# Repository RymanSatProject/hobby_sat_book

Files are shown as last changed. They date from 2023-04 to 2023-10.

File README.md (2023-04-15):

# #趣味で作る人工衛星

本リポジトリは、[オーム社 #趣味で作る人工衛星](https://www.ohmsha.co.jp/book/9784274230387/)のサポートページです。

## 構成

### [00_errata](00_errata)

書籍の正誤表が入っています。

### [01_CDH_OBC](01_CDH_OBC)

第7章C&DH系OBCソフトウェアのソースコード

### [02_Mission_OBC](02_Mission_OBC)

第7章ミッションOBCソフトウェアのソースコードおよびセットアップスクリプトが入っています。

### [03_Telecom_OBC](03_Telecom_OBC)

第7章通信OBCソフトウェアのソースコードが入っています。

### [04_Ground_Sta](04_Ground_Sta)

第7章地上局ソフトウェアのインストーラが入っています。

### [05_Schematic](05_Schematic)

第7章EM基板のKiCadファイルが入っています。回路図とCAD画像も入れてあるので、基板作成時にご参照ください。

### [10_Ch7_Sup](10_Ch7_Sup)

第7章の各種補足説明が入っています。

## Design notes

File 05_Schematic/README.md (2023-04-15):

# 回路図面

書籍で作成する基板の回路図を保存しています。使用ソフトウエアはKiCAD (https://www.kicad.org/download/) です。Version6.0以降であれば問題ないと思います。
基板制作時の部品配置や配線の参考にご利用ください。

RaspberryPi RaspberryPiの搭載されている下部基板の図面です。

esp32 Esp32の搭載されている背面基板の図面です。

stm32 STM32の搭載されている上部基板の図面です。

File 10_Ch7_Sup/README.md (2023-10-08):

# 第7章 補足説明

本フォルダ、第7章を進めるにあたって必要なソフトウェアの説明及び補足情報が入っています。

- 購入部品・工具リスト(代替部品記載有り): [こちら(Excel)](parts/RSP-01Lite_Parts_ToolList.xlsx)
- C系ソフトウェア: [sw-c.md](sw-c.md)
- T系ソフトウェア: [sw-t.md](sw-t.md)
- T系OBCとPCとの接続設定: [sw-t-pc.md](sw-t-pc.md)
- ターミナルについて: [sw-terminal.md](sw-terminal.md)
- Raspberry Pi Zeroの設定について: [pi-setting.md](pi-setting.md)
- コマンドリスト: [こちら(Excel)](design/RSP-01Lite_CommandList.xlsx)

## P144 図9でBMX055表示が出ない場合

### 1.STM32のリセットボタンを押す

STM32のB2（黒いボタン）を押すことでリセットがかかり、表示される場合があります。表示されない場合は配線が間違っている可能性があるので、もう一度配線を見直してください。

## P178 図66の組み上げ後、アームが動かない場合

### 1.モーターにコンデンサを追加する

モーターのノイズをI2Cが引き込んで動作しにくい場合があります。モーターに0.1μFのコンデンサを3個はんだ付けして見て下さい。参考写真[こちら](img/P178_fig66.jpg)

### 2.ギア、軸受けにグリスを塗布する

ギアボックスの各種ギアやシャフトの軸受けにグリスを塗布することで負荷が減ります。参考[タミヤ モリブデングリス](https://www.tamiya.com/japan/products/87022/index.html)

## P150 apt update で 404 Not Found が発生する場合
2023/10/7 時点で、``` apt update ``` を行うと以下のエラーメッセージが表示されます。

```
$ sudo apt update && sudo apt upgrade -y

Hit:1 http://archive.raspberrypi.org/debian stretch InRelease
Ign:2 http://raspbian.raspberrypi.org/raspbian stretch InRelease
Err:3 http://raspbian.raspberrypi.org/raspbian stretch Release
  404  Not Found
Reading package lists... Done
E: The repository 'http://raspbian.raspberrypi.org/raspbian stretch Release' does no longer have a Release file.
N: Updating from such a repository can't be done securely, and is therefore disabled by default.
N: See apt-secure(8) manpage for repository creation and user configuration details.
```

上記が発生した場合は、リポジトリの参照先を変更する必要があります。

```
# sources.list を開く
sudo vi /etc/apt/sources.list
```

以下のようにリポジトリの参照先を変更します。

```
#deb http://raspbian.raspberrypi.org/raspbian/ stretch main contrib non-free rpi
deb http://legacy.raspbian.org/raspbian/ stretch main contrib non-free rpi
```

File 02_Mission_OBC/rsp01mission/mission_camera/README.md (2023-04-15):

## 概要
Raspberry Pi上で動作するMission系のカメラ機能。自撮りや画像等の送信を行う。

## 必要なもの
pillowに以下のライブラリが必要
```
sudo apt-get install libopenjp2-7
```

## コーディング規則
- 文字コードはUTF-8とする。
- IntelliJ IDEAでオートフォーマットをかけるのをおすすめします。Option + Cmd + L(WindowsではAlt + Ctrl + L)

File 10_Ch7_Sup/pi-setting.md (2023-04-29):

# Raspberry Pi Zeroの設定について

Raspberry Pi Zeroの設定に関する補足事項などについて説明します。

## 1. IPアドレス
### 1.1 静的IPアドレスの設定
書籍では、Raspberry Pi ZeroのIPアドレス設定はデフォルトであるdhcpとなっています。dhcpの場合、Windowsとのインターネット共有の際にインターネット接続が可能となるまで１、２分かかる場合があります。   
静的IPアドレスの設定を行うことで、Raspberry Pi Zeroの起動後、ほぼ即座にインターネット接続状態になります。

静的IPアドレスの設定は以下の手順で行います。

1. sshなどでRaspberry Pi Zeroに接続します。
2. 以下コマンドで /etc/dhcpcd.conf を開きます。
```bash
sudo vi /etc/dhcpcd.conf
```
3. 「Example static IP configuration:」の下、47行目周辺に以下を追記し、保存終了します。（vi の操作方法はここでは割愛します）

```
interface usb0
static ip_address=192.168.137.10
static routers=192.168.137.1
static domain_name_servers=8.8.8.8
```

※routersのアドレスは、Windows側のUSB EthernetデバイスのIPアドレスを設定する事になります。（デフォルトで192.168.137.1が設定されます）   
※DNSはGoogle社のDNSを指しています。

4. 以下コマンドで /etc/network/interfaces を開きます。
```bash
sudo vi /etc/network/interfaces
```

5. ファイル末尾に以下を追記し、保存終了します。
```
auto lo usb0
allow-hotplug usb0
iface usb0 inet manual
```

6. Raspberry Pi Zeroを以下コマンドで再起動します。
```
sudo reboot
```

7. 再起動後、以下コマンドでIPアドレスの設定状態を確認します。
```
ip a
```

以下のように usb0 のIPアドレスが 192.168.137.10/24 で表示されることを確認します。

```
pi@raspberrypi:~$ ip a
1: lo: <LOOPBACK,UP,LOWER_UP> mtu 65536 qdisc noqueue state UNKNOWN group default qlen 1000
    link/loopback 00:00:00:00:00:00 brd 00:00:00:00:00:00
    inet 127.0.0.1/8 scope host lo
       valid_lft forever preferred_lft forever
    inet6 ::1/128 scope host
       valid_lft forever preferred_lft forever
2: usb0: <BROADCAST,MULTICAST,UP,LOWER_UP> mtu 1500 qdisc pfifo_fast state UP group default qlen 1000
    link/ether d6:ed:b2:e8:fc:2f brd ff:ff:ff:ff:ff:ff
    inet 192.168.137.10/24 brd 192.168.137.255 scope global usb0
       valid_lft forever preferred_lft forever
    inet6 fe80::d4ed:b2ff:fee8:fc2f/64 scope link
       valid_lft forever preferred_lft forever
```

8. pingでインターネット接続を確認します。
```
ping rymansat.com
```

以下のような応答が得られることを確認します。

```
64 bytes from www2944.sakura.ne.jp (49.212.198.184): icmp_seq=1 ttl=55 time=12.2 ms
64 bytes from www2944.sakura.ne.jp (49.212.198.184): icmp_seq=2 ttl=55 time=12.3 ms
```

## 2. インターネット接続
### 2.1 WindowsとRaspberry Piのインターネット接続の共有

インターネット接続の共有は、Windowsを再起動すると解除されます。   
再起動後もインターネット接続の共有を維持する場合は、以下の設定を行います。

1. Power Shell を管理者権限で起動します。
2. 以下のコマンドを実行します。
```
# レジストリにインターネット接続共有の永続化を設定する
New-ItemProperty -Path HKLM:\Software\Microsoft\Windows\CurrentVersion\SharedAccess -Name EnableRebootPersistConnection -Value 1 -PropertyType dword

# 「Internet Connection Sharing (ICS)」サービスを自動起動に変更する
Set-Service SharedAccess -StartupType Automatic -PassThru
```

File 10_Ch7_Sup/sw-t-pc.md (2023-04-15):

# 開発環境準備（ソフトウェア）: 通信: PCとのBluetooth接続

T系OBCとPCとのBluetooth接続の方法について説明します。

## T系OBCとPCの接続

T系OBCの電源を入れます。

PCの「設定」を開き、「デバイス」を選択します。

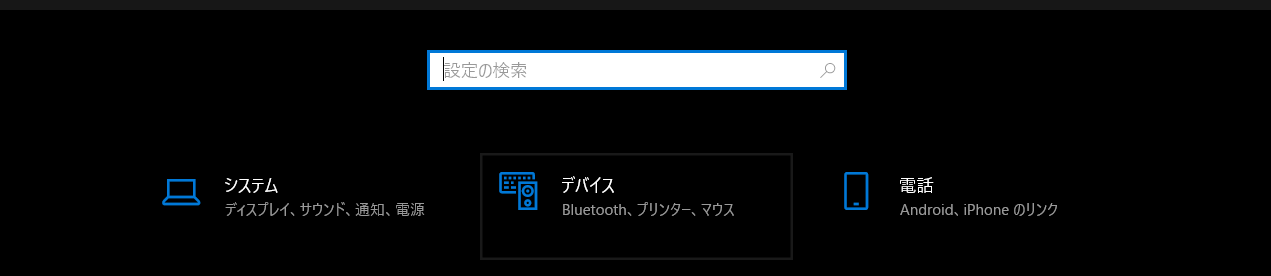
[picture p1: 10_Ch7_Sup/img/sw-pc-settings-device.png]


「Bluetoothまたはその他のデバイスを追加する」を選択します。

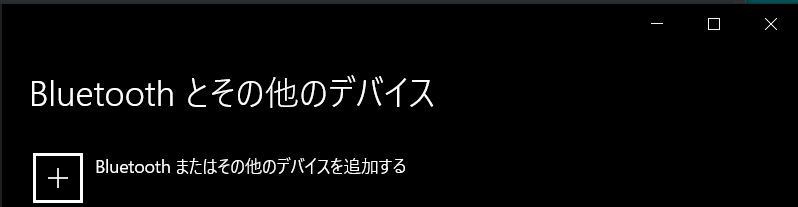
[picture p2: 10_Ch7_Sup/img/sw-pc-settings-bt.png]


「デバイスを追加する」ウィンドウで「Bluetooth」を選択します。

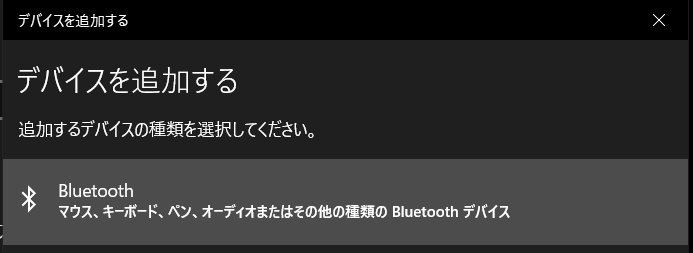
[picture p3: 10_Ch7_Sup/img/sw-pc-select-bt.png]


「01-lite」を選択すると接続開始します。うまくいくと以下のようになるので、「完了」をクリックしてウィンドウを閉じます。

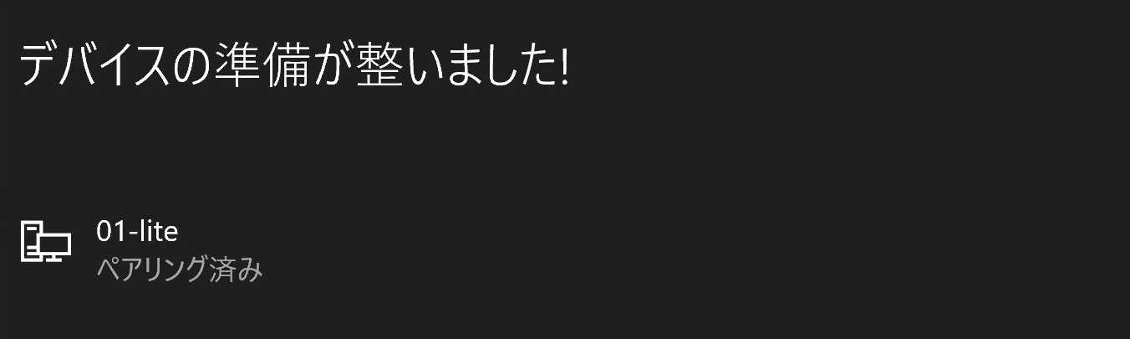
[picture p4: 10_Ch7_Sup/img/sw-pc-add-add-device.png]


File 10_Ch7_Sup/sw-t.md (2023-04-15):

# 開発環境準備（ソフトウェア）: 通信

T系OBC用ソフトウェアのビルド環境・ビルド実行・T系OBCへのインストールの方法について説明します。

# ビルド環境の準備

通信ソフトウェアはArduinoライブラリを利用しています。これのビルドとT系OBCへのアップロードにはArduino IDEを使用します。

## Arduino IDEのインストール

[https://www.arduino.cc/en/software](https://www.arduino.cc/en/software) に行き、「DOWNLOAD OPTIONS」のうち「Windows Win 10 and newer, 64 bits」を選択してダウンロード・インストールします。

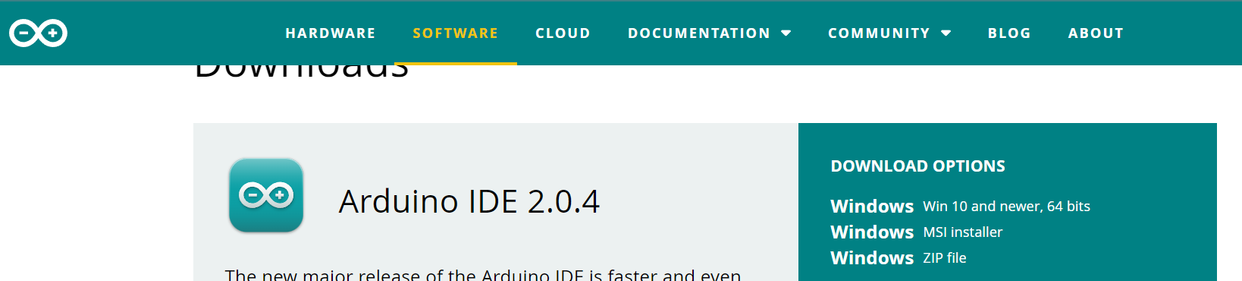
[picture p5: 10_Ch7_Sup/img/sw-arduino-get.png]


インストール後、スタートメニューから「Arduino IDE」をクリックして起動します。

起動後、以下の画面が現れたら、「プライベートネットワーク」の方にチェックを入れて「アクセスを許可する」をクリックします。

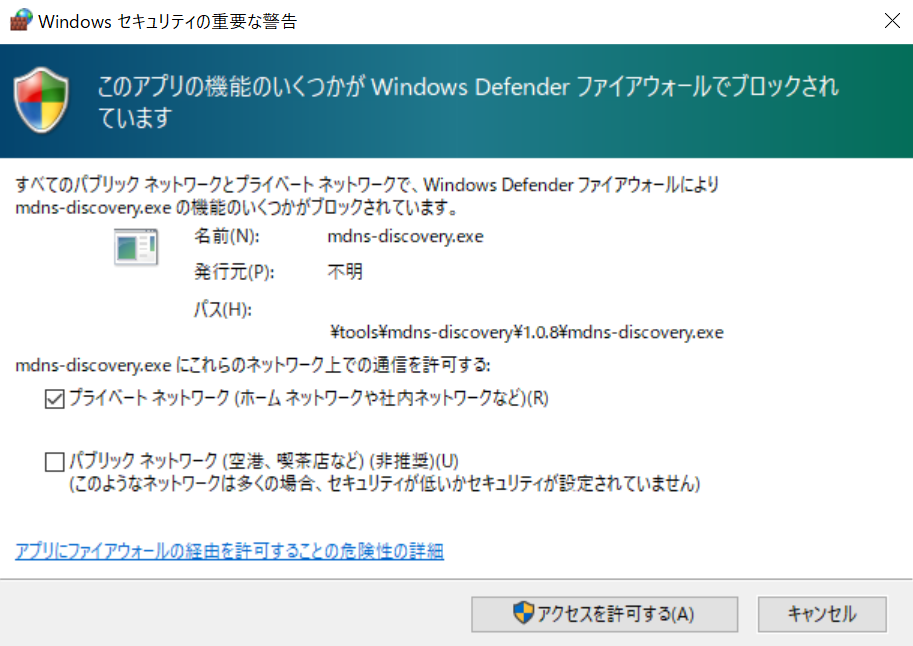
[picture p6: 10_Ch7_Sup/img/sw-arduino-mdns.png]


また、以下のようにいくつかインストールが求められますが、いずれも「インストール」を選択しておきます。

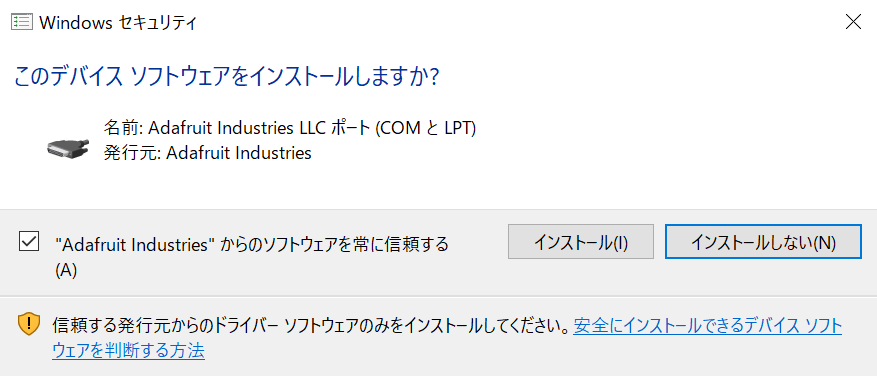
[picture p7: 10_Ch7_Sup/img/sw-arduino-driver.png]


最後に、Arduino IDEのメニューバーで「File」→「Preferences」をクリックし、設定画面を開きます。

表示言語を日本語に変更するため、「Language」で「日本語」を選択して「OK」をクリックします。

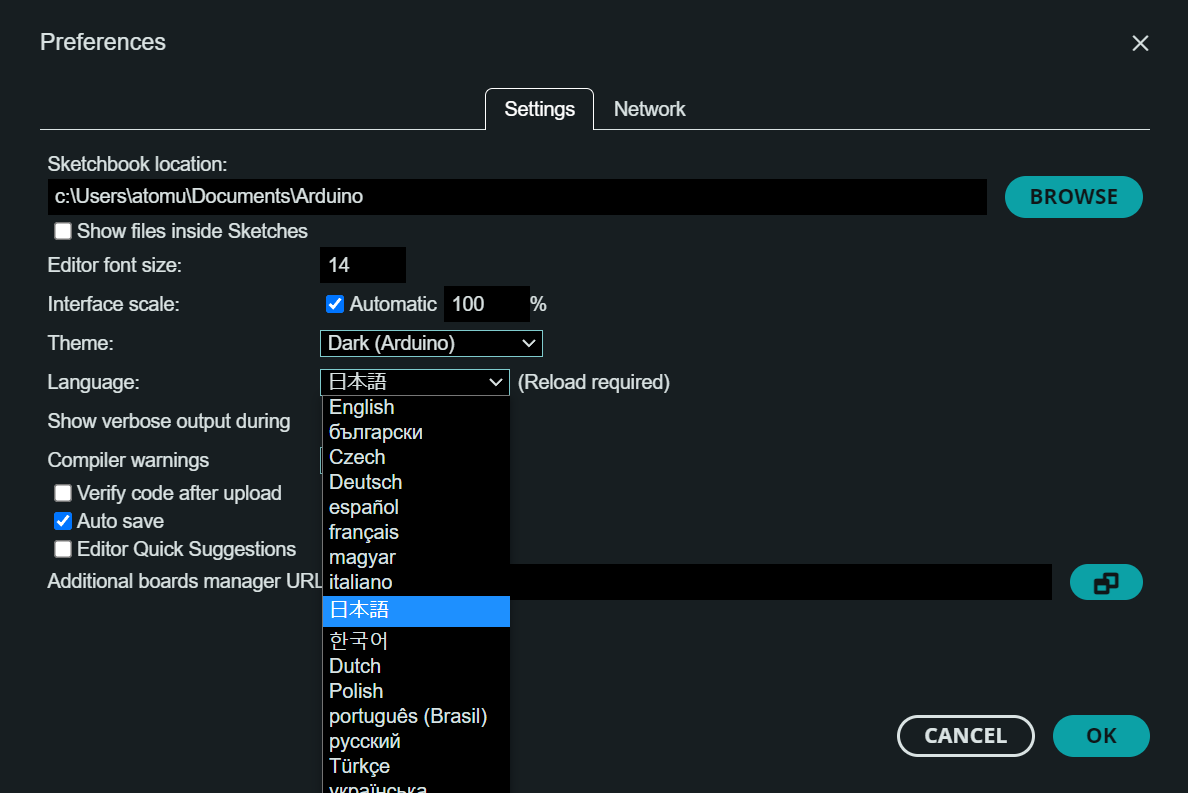
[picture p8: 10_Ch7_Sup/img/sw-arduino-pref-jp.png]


するとArduino IDEが自動的に再起動し、表示が日本語に切り替わります。

## ライブラリの追加

通信ソフトウェアで利用されるarduino-esp32ライブラリインストールします。

[https://docs.espressif.com/projects/arduino-esp32/en/latest/installing.html](https://docs.espressif.com/projects/arduino-esp32/en/latest/installing.html) にアクセスし、「Stable release link」に記載されたURLをコピーします。（本稿執筆段階でのURLは`https://raw.githubusercontent.com/espressif/arduino-esp32/gh-pages/package_esp32_index.json`です）

続けて、Arduino IDEのメニューバーで「ファイル」→「基本設定...」をクリックし、設定画面を開きます。

「追加のボードマネージャのURL」に先程コピーしたURLを貼り付け、「OK」をクリックします。

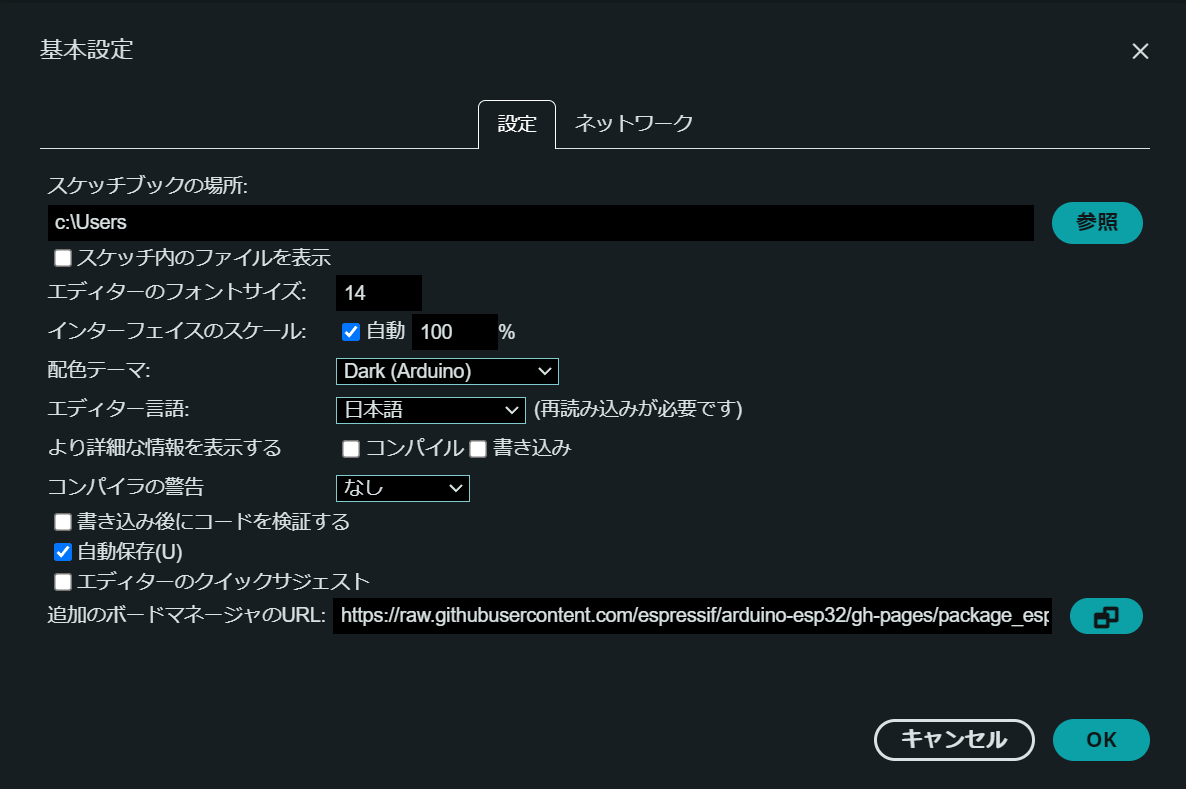
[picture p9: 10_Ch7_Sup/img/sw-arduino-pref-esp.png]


その後、Arduino IDEのメニューバーで「ツール」→「ボード」→「ボードマネージャ」をクリックし、ボードマネージャを開きます。

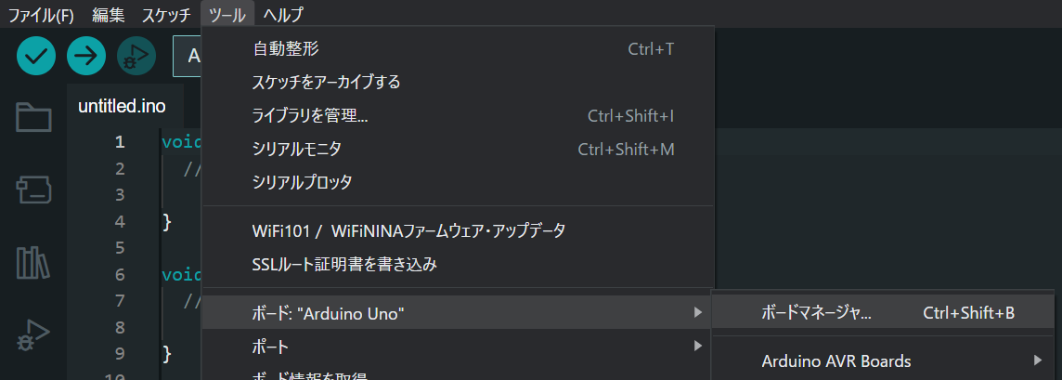
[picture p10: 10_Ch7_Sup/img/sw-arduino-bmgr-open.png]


この中から「esp32 by Espressif Systems」を見つけます（「es」と検索するとすぐに出てきます）。そして図のようにバージョン2.0.2を選択して「インストール」をクリックします。（クリックするとバージョン選択が元に戻りますが、インストールされるのは選択した2.0.2となります）

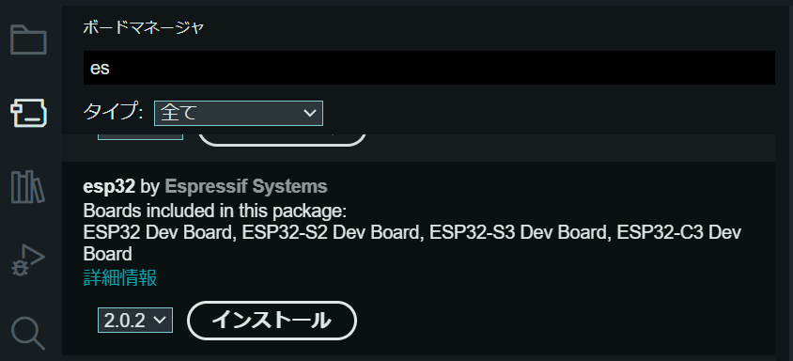
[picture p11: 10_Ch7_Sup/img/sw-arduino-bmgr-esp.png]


## ソースコードの取得

以下のいずれかの方法でソースコードを取得します。

### GitHubからzipファイルをダウンロードする

本GitHubページのトップで「Code」をクリックし、「Download ZIP」でzipファイルをダウンロード・解凍します。

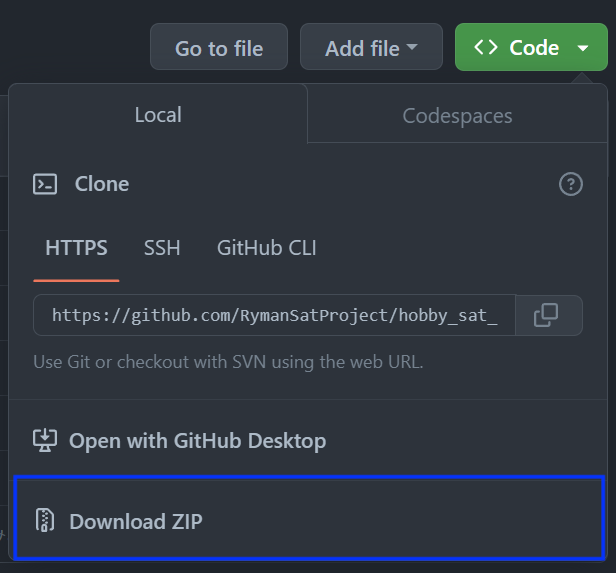
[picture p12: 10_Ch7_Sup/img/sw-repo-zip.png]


### `git`コマンドを使う

[開発環境準備（ソフトウェア）: C系](sw-c.md)に記述のようにUbuntuを導入済みの場合は、`git`コマンドを使って**Windows側のファイルシステムに**リポジトリを取得できます。

```bash
# Windows側に移動する。移動先が「ドキュメント」フォルダの場合は以下
cd /mnt/c/Users/user/Documents

# リポジトリを取得
git clone https://github.com/RymanSatProject/hobby_sat_book.git
```

（**注意**: Arduino IDEは、WSL上のLinuxファイルシステム配下のソースファイルを開くことができません。ソースファイルはWindowsのファイルシスステム配下に直接置く必要があります。）

# ビルドの実行

エクスプローラで取得したフォルダ中の`03_Telecom_OBC\esp32\esp32.ino`をArduino IDEで開きます。

下図のように、Arduino IDEのメニューバーで「ツール」→「ボード」→「esp32」とたどり、「ESP32 Dev Module」をクリックします。

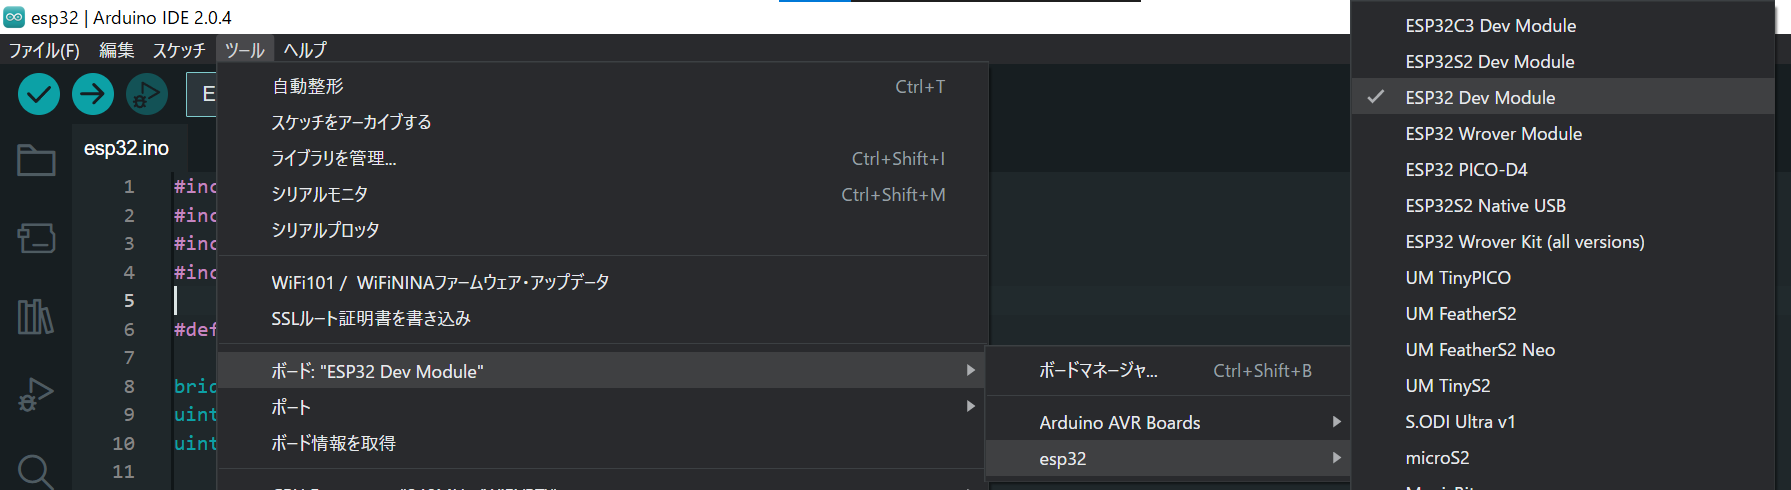
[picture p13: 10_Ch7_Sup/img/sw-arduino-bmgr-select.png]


そして画面左上のチェックマークをクリックするか、`Ctrl + r` でビルドを実行します。ビルドには1分程度の時間がかかります。

画面下側の黒い出力画面で

```text
最大1310720バイトのフラッシュメモリのうち、スケッチが259073バイト（19%）を使っています。
最大327680バイトのRAMのうち、グローバル変数が19356バイト（5%）を使っていて、ローカル変数で308324バイト使うことができます。
```

のように出力されれば成功です。

# アップロード

まず、T系OBCをPCから外した状態で、Arduino IDEのメニューバーの「ツール」→「シリアルポート」にマウスを移動し、どのポートが存在するか確認します。

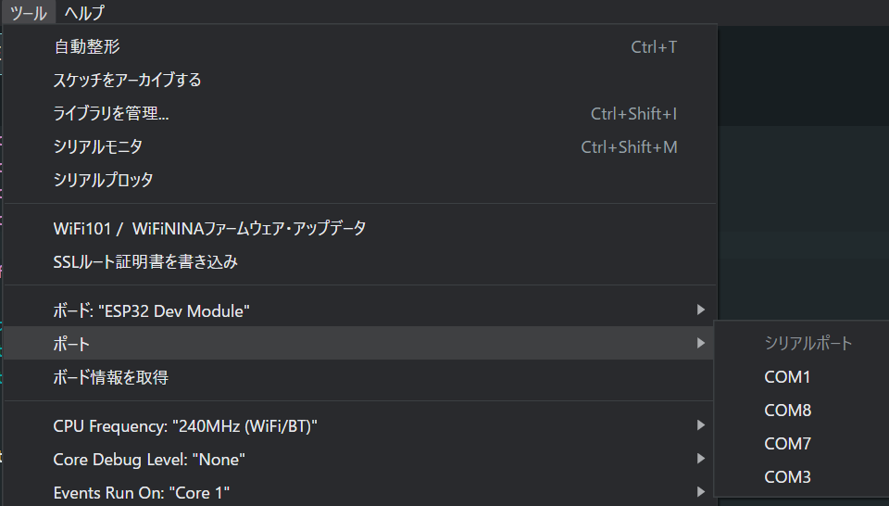
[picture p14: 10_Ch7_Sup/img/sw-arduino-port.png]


続けてT系OBCとPCをUSBケーブルで接続し、同じように「ツール」→「シリアルポート」を確認します。PCがESP32を正しく認識していると、下図のようにポートが1つ増えているはずです。

この新しく増えたポートをクリックし、書き込み先ポートを決定します。

ポートが追加されていない場合は、PCがT系OBCを認識していない可能性があります。この場合はT系OBCをPCから外し、再度接続してみてください。

続けて、画面左上の右矢印ボタンを押すか、`Ctrl + u`を押すと、プログラムのビルドとアップロードが始まります。

「出力」に

```text
Leaving...
Hard resetting via RTS pin...
```

と表示されれば書き込み成功です。

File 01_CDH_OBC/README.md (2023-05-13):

# 簡易RSP-01 Main OBCソフトウェア

本ディレクトリには、第7章のMain OBC用ソフトウェアのソースコードが格納されています。

このソフトウェアは、RSP-01における実装を参考に書き直しを行ったものです。

環境設定・ビルドの方法は[10_Ch7_Sup/sw-c.md](/10_Ch7_Sup/sw-c.md)を参照ください。

## ターミナルでの文字入力

Main OBCにT系OBCが接続されていないか、T系OBCとの接続が不安定な場合、ターミナルには通信失敗を示す以下のようなメッセージが約1秒周期で表示されます:

```text
[ERR] comm.handshake: timeout
[ERR] transact: failed: cmd=0x10 ret=1
```

このとき、キーボードからの入力の取りこぼしが発生しやすくなります。取りこぼしを回避するためには、上記メッセージの合間に1文字ずつ入力してください。

文字入力に成功すると、入力文字がエラーメッセージの間に割り込む形で表示されます。下図は`debug 1`の入力に成功した場合の例です:

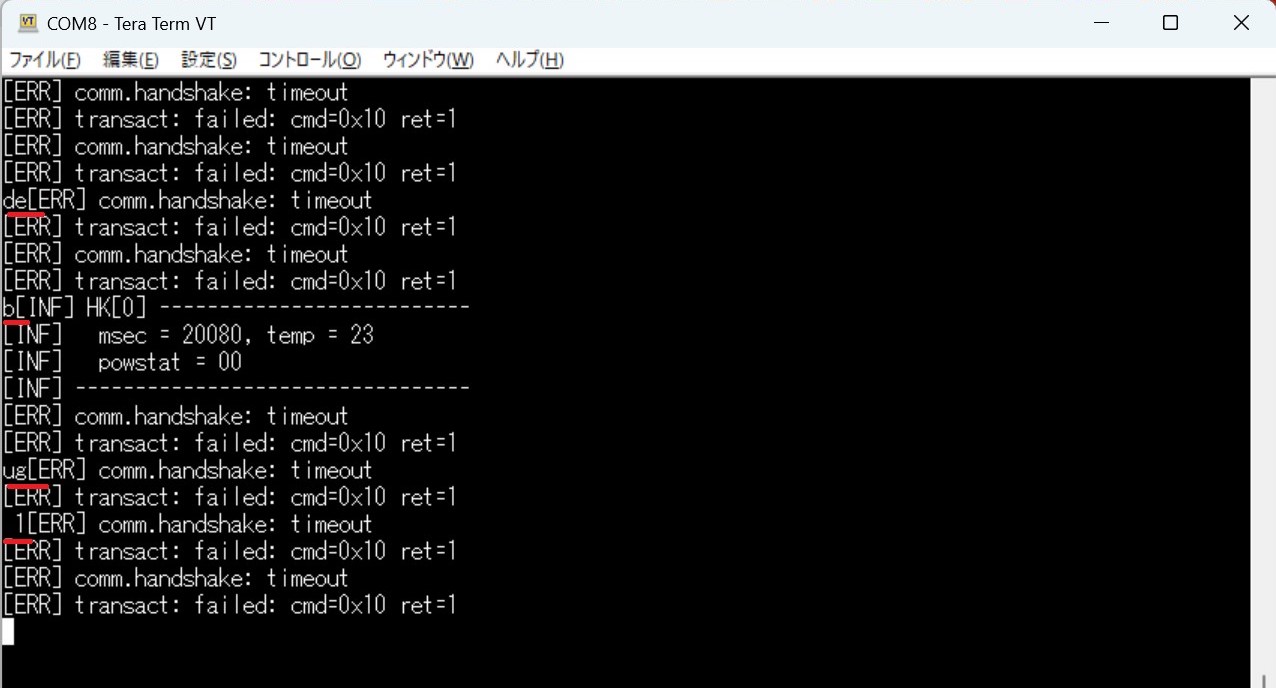
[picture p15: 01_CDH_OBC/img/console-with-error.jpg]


入力した文字が表示されない場合は取りこぼしが発生しているので、エラーメッセージの合間に`Ctrl + c`を入力して入力をキャンセルし、再度入力を試みてください。

## 設定の変更

### アームのパラメータ変更

`src/config/config.hpp`には、アームの挙動に関係するいくつかのパラメータが定義されています。必要に応じて変更してください。

- `DRIVE_FORWARD_LIMIT`, `DRIVE_REVERSE_LIMIT`:
  - アーム展開・収納時に、アーム駆動部（書籍図62中の３番パーツで構成される部分）が軸（書籍図62中の25番パーツ）に対してどの程度端まで到達するかを決めるパラメータです。0は完全に展開しきった位置、65535は完全に収納しきった位置を示します。
  - 値の範囲は以下に従ってください:
    - 0以上65535以内
    - 大きさの関係: `DRIVE_FORWARD_LIMIT` < `DRIVE_REVERSE_LIMIT`
  - 例えば、アームの展開長を小さくしたい場合は`DRIVE_FORWARD_LIMIT`をより大きな値にしてください。

- `DRIVE_TIME_MS`: 1回の展開/収納動作に使われる最大継続時間（ミリ秒）。駆動時間が長すぎる・短すぎる場合は変更してください

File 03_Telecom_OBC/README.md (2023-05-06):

# 簡易RSP-01 T系OBCソフトウェア

本ディレクトリには、第7章のT系OBC用ソフトウェアのソースコードが格納されています。

このソフトウェアは、RPS-01における実装を参考に書き直しを行ったものです。

環境設定・ビルドの方法は[10_Ch7_Sup/sw-t.md](/10_Ch7_Sup/sw-t.md)を参照ください。

PCとのBluetooth接続の方法については[10_Ch7_Sup/sw-t-pc.md](/10_Ch7_Sup/sw-t-pc.md)を参照ください。

## 設定の変更

### ブザーの音量を小さくする

ブザーの音量は、`esp32/src/common/config.hpp`中の`CW_VOLUME_PERCENT`で設定されます。音を大きくするには100までの大きな値を、小さくするには0以上の小さな値を設定し、再度ビルド・アップロードしてください。

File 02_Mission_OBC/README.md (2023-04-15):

# ミッション系

本ディレクトリには、第7章のM系Raspberry Pi Zeroにインストールするソフトウェアが格納されています。   
書籍の手順に従い、ZIPファイルをダウンロードし、インストールを行ってください。

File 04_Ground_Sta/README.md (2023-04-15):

# 地上局

本ディレクトリには、第7章の地上局ソフトウェアである「TestCamp Lite（テストキャンプ ライト）」が格納されています。

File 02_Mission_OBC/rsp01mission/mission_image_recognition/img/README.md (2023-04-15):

# 切り出しメモ
## Earth Seen From Space Station ISS [Real Speed HD].mp4

```bash
ffmpeg -ss 192 -i Earth\ Seen\ From\ Space\ Station\ ISS\ \[Real\ Speed\ HD\].mp4 -t 100 ../001.mp4
ffmpeg -ss 400 -i Earth\ Seen\ From\ Space\ Station\ ISS\ \[Real\ Speed\ HD\].mp4 -t 80 ../002.mp4
ffmpeg -ss 705 -i Earth\ Seen\ From\ Space\ Station\ ISS\ \[Real\ Speed\ HD\].mp4 -t 90 ../003.mp4
ffmpeg -ss 833 -i Earth\ Seen\ From\ Space\ Station\ ISS\ \[Real\ Speed\ HD\].mp4 -t 80 ../004.mp4
ffmpeg -ss 1068 -i Earth\ Seen\ From\ Space\ Station\ ISS\ \[Real\ Speed\ HD\].mp4 -t 80 ../005.mp4
ffmpeg -ss 1388 -i Earth\ Seen\ From\ Space\ Station\ ISS\ \[Real\ Speed\ HD\].mp4 -t 60 ../006.mp4
```

## 国際宇宙ステーション（ISS）から撮影した夜の地球 【Full HD 1080p】.mp4

```bash
ffmpeg -ss 30 -i 国際宇宙ステーション（ISS）から撮影した夜の地球\ 【Full\ HD\ 1080p】.mp4 -t 13 ../007.mp4
ffmpeg -ss 140 -i 国際宇宙ステーション（ISS）から撮影した夜の地球\ 【Full\ HD\ 1080p】.mp4 -t 17 ../008.mp4
ffmpeg -ss 159 -i 国際宇宙ステーション（ISS）から撮影した夜の地球\ 【Full\ HD\ 1080p】.mp4 -t 9 ../009.mp4
ffmpeg -ss 170 -i 国際宇宙ステーション（ISS）から撮影した夜の地球\ 【Full\ HD\ 1080p】.mp4 -t 14 ../010.mp4
ffmpeg -ss 198 -i 国際宇宙ステーション（ISS）から撮影した夜の地球\ 【Full\ HD\ 1080p】.mp4 -t 12 ../011.mp4
ffmpeg -ss 225 -i 国際宇宙ステーション（ISS）から撮影した夜の地球\ 【Full\ HD\ 1080p】.mp4 -t 8 ../012.mp4
ffmpeg -ss 235 -i 国際宇宙ステーション（ISS）から撮影した夜の地球\ 【Full\ HD\ 1080p】.mp4 -t 6 ../013.mp4
ffmpeg -ss 243 -i 国際宇宙ステーション（ISS）から撮影した夜の地球\ 【Full\ HD\ 1080p】.mp4 -t 15 ../014.mp4
ffmpeg -ss 270 -i 国際宇宙ステーション（ISS）から撮影した夜の地球\ 【Full\ HD\ 1080p】.mp4 -t 15 ../015.mp4
```

## 【 ISS 】 国際宇宙ステーション 日本上空を飛行.mp4
全編を 016.mp4 として使う

## 宇宙から撮影された地球【Full HD 1080p】.mp4

```bash
ffmpeg -ss 165 -i 宇宙から撮影された地球【Full\ HD\ 1080p】.mp4 -t 23 ../017.mp4
ffmpeg -ss 730 -i 宇宙から撮影された地球【Full\ HD\ 1080p】.mp4 -t 51 ../018.mp4
ffmpeg -ss 730 -i fin/宇宙から撮影された地球【Full\ HD\ 1080p】.mp4 -t 19 ../018_1.mp4
ffmpeg -ss 750 -i fin/宇宙から撮影された地球【Full\ HD\ 1080p】.mp4 -t 30 ../018_2.mp4
ffmpeg -ss 796 -i 宇宙から撮影された地球【Full\ HD\ 1080p】.mp4 -t 20 ../019.mp4
ffmpeg -ss 864 -i 宇宙から撮影された地球【Full\ HD\ 1080p】.mp4 -t 15 ../020.mp4
ffmpeg -ss 881 -i 宇宙から撮影された地球【Full\ HD\ 1080p】.mp4 -t 20 ../021.mp4
ffmpeg -ss 911 -i 宇宙から撮影された地球【Full\ HD\ 1080p】.mp4 -t 15 ../022.mp4
ffmpeg -ss 928 -i 宇宙から撮影された地球【Full\ HD\ 1080p】.mp4 -t 16 ../023.mp4
```

## NASA - Earth view from ISS - 1080p60 HD - (time lapse).mp4

```bash
ffmpeg -ss 13 -i NASA\ -\ Earth\ view\ from\ ISS\ -\ 1080p60\ HD\ -\ \(time\ lapse\).mp4 -t 23 ../024.mp4
ffmpeg -ss 43 -i NASA\ -\ Earth\ view\ from\ ISS\ -\ 1080p60\ HD\ -\ \(time\ lapse\).mp4 -t 13 ../025.mp4
ffmpeg -ss 346 -i NASA\ -\ Earth\ view\ from\ ISS\ -\ 1080p60\ HD\ -\ \(time\ lapse\).mp4 -t 54 ../026.mp4
ffmpeg -ss 441 -i NASA\ -\ Earth\ view\ from\ ISS\ -\ 1080p60\ HD\ -\ \(time\ lapse\).mp4 -t 16 ../027.mp4
ffmpeg -ss 467 -i NASA\ -\ Earth\ view\ from\ ISS\ -\ 1080p60\ HD\ -\ \(time\ lapse\).mp4 -t 19 ../028.mp4
ffmpeg -ss 496 -i NASA\ -\ Earth\ view\ from\ ISS\ -\ 1080p60\ HD\ -\ \(time\ lapse\).mp4 -t 15 ../029.mp4
ffmpeg -ss 589 -i NASA\ -\ Earth\ view\ from\ ISS\ -\ 1080p60\ HD\ -\ \(time\ lapse\).mp4 -t 18 ../030.mp4
ffmpeg -ss 607 -i NASA\ -\ Earth\ view\ from\ ISS\ -\ 1080p60\ HD\ -\ \(time\ lapse\).mp4 -t 3 ../031.mp4
ffmpeg -ss 732 -i NASA\ -\ Earth\ view\ from\ ISS\ -\ 1080p60\ HD\ -\ \(time\ lapse\).mp4 -t 3 ../032.mp4
ffmpeg -ss 753 -i NASA\ -\ Earth\ view\ from\ ISS\ -\ 1080p60\ HD\ -\ \(time\ lapse\).mp4 -t 27 ../033.mp4
ffmpeg -ss 960 -i NASA\ -\ Earth\ view\ from\ ISS\ -\ 1080p60\ HD\ -\ \(time\ lapse\).mp4 -t 18 ../034.mp4
ffmpeg -ss 984 -i NASA\ -\ Earth\ view\ from\ ISS\ -\ 1080p60\ HD\ -\ \(time\ lapse\).mp4 -t 14 ../035.mp4
ffmpeg -ss 1130 -i NASA\ -\ Earth\ view\ from\ ISS\ -\ 1080p60\ HD\ -\ \(time\ lapse\).mp4 -t 27 ../036.mp4
ffmpeg -ss 1506 -i NASA\ -\ Earth\ view\ from\ ISS\ -\ 1080p60\ HD\ -\ \(time\ lapse\).mp4 -t 35 ../037.mp4
```

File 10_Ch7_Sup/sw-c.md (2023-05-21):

# 開発環境準備（ソフトウェア）: C系

Main OBC用ソフトウェアのビルド環境・ビルド実行・Main OBCへのインストールの方法について説明します。

# ビルド環境の準備

C系ソフトウェアのビルド環境は、WindowsのWindows Subsystem for Linux (WSL) という機能を使って構築します。

本作業は1時間〜数時間程度の時間がかかります。一度完了すれば、ほとんどの工程は繰り返す必要はありません。

すでに同様の環境およびツールがインストール済みの場合は、適宜スキップしてください。

## Ubuntuのインストール

### Linux機能の有効化

「Windowsの機能の有効化または無効化」を開きます。

「スタート」（Windowsマーク）をクリックし、そのまま半角入力モードで「windows」と入力します。すると、下図のように「Windowsの機能の有効化または無効化」が現れるので、それをクリックして開きます。

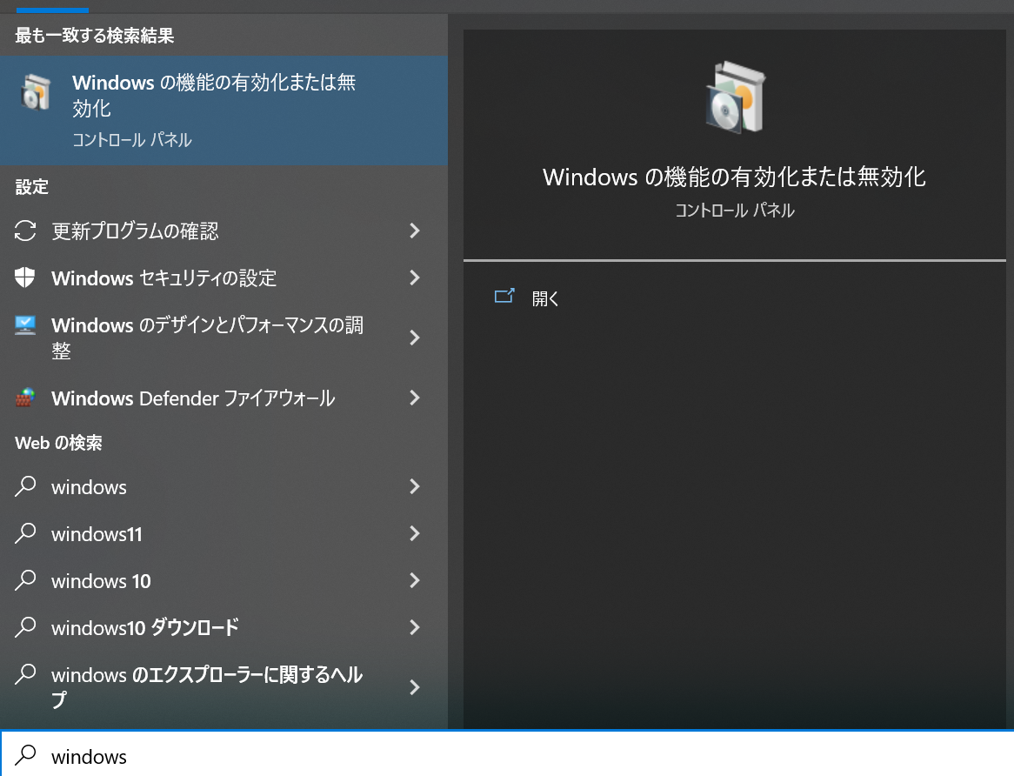
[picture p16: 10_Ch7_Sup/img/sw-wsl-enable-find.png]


以下の2つの項目を見つけ、それぞれチェックマークを入れます:

- 「Linux用Windowsサブシステム」
- 「仮想マシン プラットフォーム」

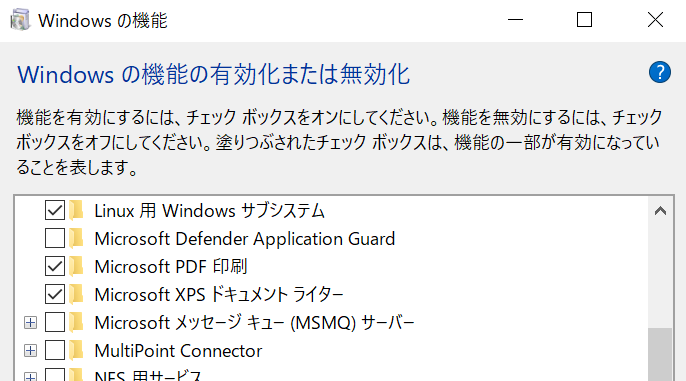
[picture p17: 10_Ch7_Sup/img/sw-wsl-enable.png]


その後、OKをクリックし、PCを再起動します。

### Ubuntuのインストールと初期化

PCの再起動後、Microsoft Storeを開きます。（上と同様に「スタート」から「store」と検索します）

「ubuntu 20.04」と検索し、「Ubuntu 20.04.5 LTS」を見つけます。

表示された「Ubuntu 20.04.5 LTS」の「入手」をクリックし、ダウンロード・インストールします。

※2023/5/21時点、Microsoft Storeにて「Ubuntu 20.04.5 LTS」は表示されず「Ubuntu 20.04.6 LTS」が表示されます。   
「Ubuntu 20.04.6 LTS」でも動作チェック済みですので、「Ubuntu 20.04.6 LTS」をダウンロード・インストールしてください。

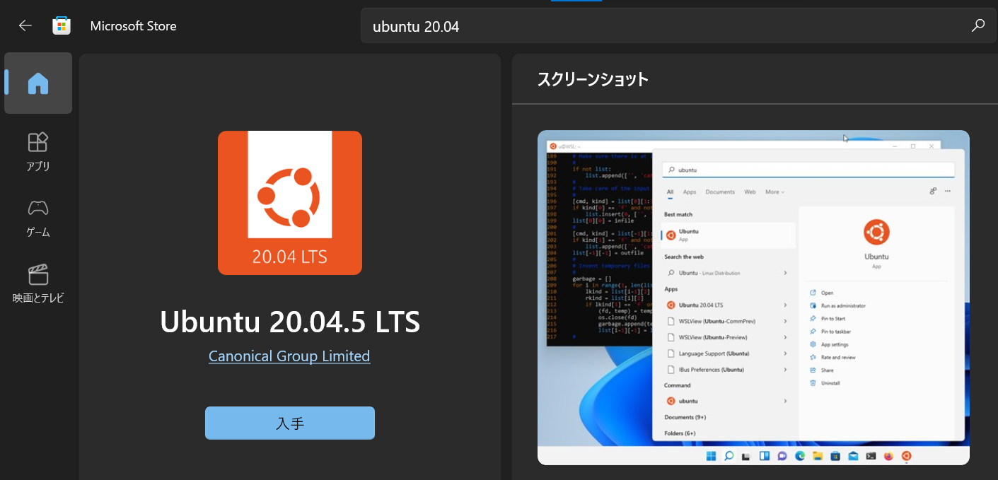
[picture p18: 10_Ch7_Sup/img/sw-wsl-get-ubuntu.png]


完了すると、スタートメニューに「Ubuntu 20.04.5 LTS」が現れるので、それをクリックして起動します。

すると以下の画面が現れ、セットアップが開始します。ユーザー名とパスワードの入力が求められるので、半角入力モードで適宜入力・エンターを押して確定します。

- ユーザー名は、Ubuntuの使用時に用いられるものです。Windowsでのユーザー名と異なっても問題ありません。
- パスワード入力時は画面には文字が現れないことに注意してください。
- 入力したパスワードは後で使うので覚えておいてください。

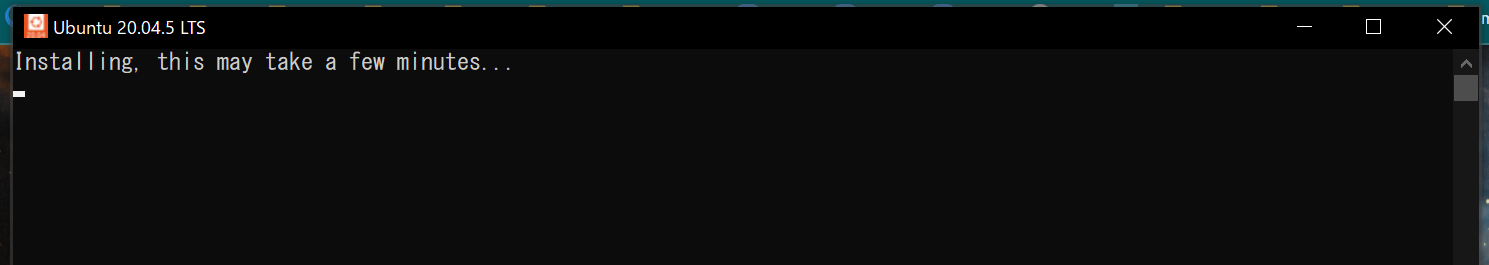
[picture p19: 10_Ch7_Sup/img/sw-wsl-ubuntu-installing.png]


セットアップ完了後、この画面を閉じます。

### Windows Terminalのインストール

Windows Terminalは、複数のターミナルソフトを一括して扱えるアプリです。上記で開いたUbuntu専用のターミナルよりも使い勝手が良いため、本稿ではこちらを使用します。

上と同様にMicrosoft Storeを開き、「terminal」と検索して「Windows Terminal」を見つけ、入手・インストールします。

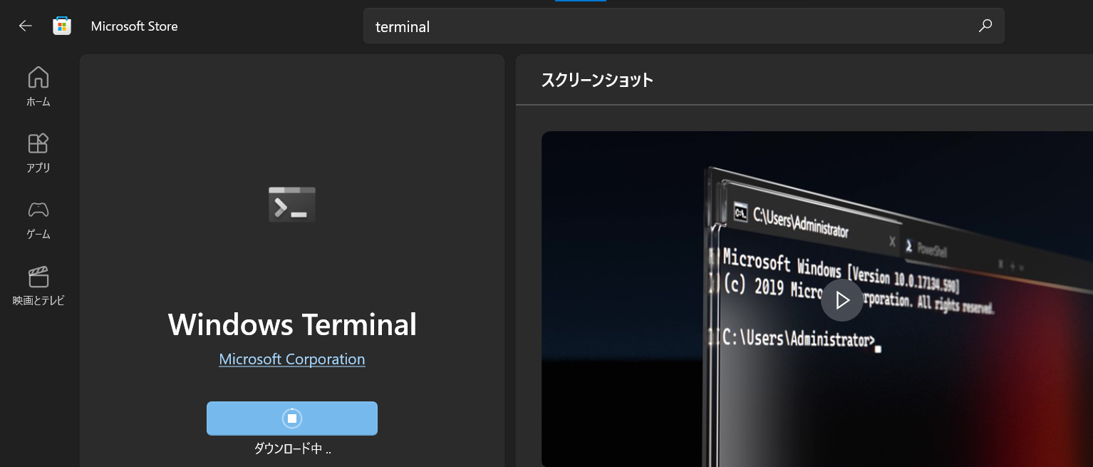
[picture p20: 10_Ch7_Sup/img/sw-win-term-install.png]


インストール後はスタートメニューにWindows Terminalが追加されているので、それをクリックして起動します。

起動後、ウィンドウ中のタブの「+」の右横にある「`v`」ボタンをクリックし、以下のように複数の選択肢を表示します。このうち「Ubuntu 20.04.5 LTS」をクリックし、Ubuntuのターミナルを立ち上げます。

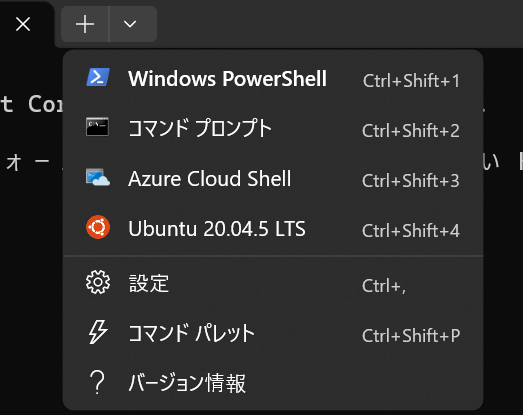
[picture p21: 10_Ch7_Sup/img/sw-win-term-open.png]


すると新しいタブが開き、`先程設定したユーザー名@PCの名前`の表示された行が現れます。



以下では、コマンドを実行する作業は全て、このWindows Terminal上の画面を使って行います。

## Ubuntuにおけるビルド環境の構築

C系ソフトウェアは、mbed-cliというツールを使ってビルドします。ここでは、それの実行に必要なソフトウェアを順次インストールします。

### ライブラリ・各種プログラムのインストール

上で開いたUbuntuの画面で以下を入力し、mbed-cliに必要なライブラリやプログラムをインストールします（`sudo apt ...`の行`#`部はコメントです）。行数が長いことに注意してください。

インストールには数分〜数十分程度の時間がかかります。なおパスワードが求められたら、ユーザーを設定した際に入力したパスワードを入力します。なおパスワード入力中に文字は何も表示されないことに注意してください。

```bash
# インストール元のリストを更新する
sudo apt update

# インストールを実行する
sudo apt install -y libffi-dev libssl-dev zlib1g-dev liblzma-dev tk-dev libbz2-dev libreadline-dev libsqlite3-dev libopencv-dev build-essential git mercurial gcc-arm-none-eabi
```

### pyenvのインストール

pyenvは、`mbed-cli`の適合するPythonのバージョンを管理するために使用します。

上の手順に続けて、Ubuntuの画面で以下を順に実行します:

```bash
git clone https://github.com/pyenv/pyenv.git ~/.pyenv
echo 'source ~/.bashrc' >> ~/.bash_profile
echo 'export PYENV_ROOT="$HOME/.pyenv"' >> ~/.bash_profile
echo 'export PATH="$PYENV_ROOT/bin:$PYENV_ROOT/shims:$PATH"' >> ~/.bash_profile
echo 'eval "$(pyenv init -)"' >> ~/.bash_profile
```

完了後、設定を更新するために、タブの`×`ボタンをクリックして現在の画面を閉じ、その後再度Ubuntuの画面を開きます。（タブ右横の「`v`」ボタン→「Ubuntu 20.04.5 LTS」をクリック）

そして以下を実行し、Pythonの指定バージョンをインストールします。これには数分程度の時間がかかります。

```bash
# Python 3.8.12をインストールする
pyenv install 3.8.12

# Python 3.8.12をこのPCで使うように設定する
pyenv global 3.8.12
```

完了後、同じ画面上で`python --version`と打ったときに`Python 3.8.12`と表示されれば成功です。

```bash
python --version
Python 3.8.12
```

### mbed-cliのインストール

以下のコマンドを実行してmbed-cliをインストールします。

```bash
pip install mbed-cli
```

完了後、同じ画面で`mbed`と打ったときに以下のような表示が見えれば成功です。

```text
usage: mbed [-h] [--version]             ...

Command-line code management tool for ARM mbed OS - http://www.mbed.com
version 1.10.5

Use "mbed <command> -h|--help" for detailed help.
Online manual and guide available at https://github.com/ARMmbed/mbed-cli
...
```

### ソースコードの取得と初期化

以下のコマンドを実行し、本稿の含まれるリポジトリ"hobby_sat_book"を取得します。

```bash
git clone https://github.com/RymanSatProject/hobby_sat_book.git
```

C系ソフトウェアが格納されたフォルダに移動します。

```bash
cd hobby_sat_book/01_CDH_OBC
```

`cd`コマンドの成功を確認するため、現在のフォルダの場所を表示する`pwd`コマンドを打って、`***/hobby_sat_book/01_CDH_OBC`のように表示されるか確認してください:

```bash
# 現在の自分の場所を表示する
pwd

# 例えば以下のように表示される
/home/user/hobby_sat_book/01_CDH_OBC
```

なお、同じ場所をエクスプローラで表示するには`explorer.exe .`を実行します。すると新しいエクスプローラのウィンドウが立ち上がり、`01_CDH_OBC`フォルダが現れるはずです。

確認ができたら、`mbed deploy`を実行し、Main OBCに必要なmbedのライブラリを取得します。これには10分程度の時間がかかります。

```bash
mbed deploy
```

完了すると、同じ場所に`mbed-os`というフォルダが生成され、その中にmbedライブラリのソースファイル群が見つかります。以下の様にコマンド`ls -l`を実行するとそれが見えます。

```bash
# mbed-osフォルダの中身を表示する
ls -l mbed-os
-rw-r--r--  1 user user    451 Mar 21 18:09 CONTRIBUTING.md
-rw-r--r--  1 user user    254 Mar 21 18:09 DOXYGEN_FRONTPAGE.md
-rw-r--r--  1 user user     73 Mar 21 18:09 Jenkinsfile
-rw-r--r--  1 user user   9115 Mar 21 18:09 LICENSE-apache-2.0.txt
-rw-r--r--  1 user user   3756 Mar 21 18:09 LICENSE.md
-rw-r--r--  1 user user   2927 Mar 21 18:09 README.md
drwxr-xr-x 21 user user   4096 Mar 21 18:09 TESTS
drwxr-xr-x  5 user user   4096 Mar 21 18:09 TEST_APPS
drwxr-xr-x 12 user user   4096 Mar 21 18:09 UNITTESTS
```

続いて以下を実行し、追加で必要なライブラリのインストールを実行します。

```bash
pip install -r mbed-os/requirements.txt
```

メッセージの最後に「WARNING: You are using pip version ...」と表示される場合がありますが無視して構いません。

# ビルドの実行

上に引き続き、`mbed compile`でプログラムのビルドを実行します。ビルドには数分程度の時間がかかります。

```text
# ビルド実行
mbed compile

# 以下のようなメッセージが順次表示される
[mbed] Working path "/home/user/01-book/hobby_sat_book/01_CDH_OBC" (program)

...
Compile [ 54.0%]: stm32f4xx_hal_mmc.c
Compile [ 54.3%]: stm32f4xx_hal_rcc.c
Compile [ 54.7%]: stm32f4xx_hal_sai.c
Compile [ 55.0%]: stm32f4xx_hal_pcd.c
...
```

以下のように、最終行に`Total Flash memory ...`と出力されればビルド成功です。

```text
...
Compile [100.0%]: terminal.cpp
Link: 01_CDH_OBC
Elf2Bin: 01_CDH_OBC
| Module | .text     | .data | .bss    |
| ------ | --------- | ----- | ------- |
| [fill] | 170(+170) | 6(+6) | 29(+29) |
...
| Subtotals        | 89100(+89100) | 2776(+2776) | 12880(+12880) |
Total Static RAM memory (data + bss): 15656(+15656) bytes
Total Flash memory (text + data): 91876(+91876) bytes

Image: ./BUILD/NUCLEO_F401RE/GCC_ARM-PROFILE/01_CDH_OBC.bin
```

もし、以下のエラー

```text
ImportError: cannot import name 'soft_unicode' from 'markupsafe'
```

が発生する場合は、以下の2行を順に実行してください（[参考](https://github.com/aws/aws-sam-cli/issues/3661)）:

```bash
pip uninstall MarkupSafe
pip install MarkupSafe==2.0.1
```

# OBCへのアップロード

上記のビルド成功メッセージの最終行にある`01_CDH_OBC.bin`が、Main OBCにアップロードするバイナリ（コンパイルされたプログラム）になります。まずは、これをエクスプローラで表示するため、現在のフォルダをエクスプローラで開いておきます。

上の作業と同じUbuntuの画面で、以下を実行します:

```bash
explorer.exe .
```

すると`01_CDH_OBC`フォルダがエクスプローラで表示されます。この中で`BUILD\NUCLEO_F401RE\GCC_ARM-PROFILE`をたどり、`01_CDH_OBC.bin`が見つかることを確認します。

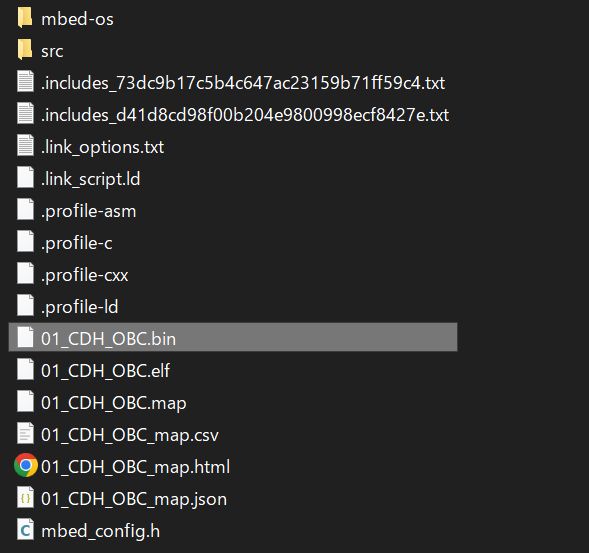
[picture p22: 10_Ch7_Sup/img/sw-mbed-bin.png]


続けて、Main Main OBCとPCをUSBケーブルで接続します。接続に成功すると、以下のようにエクスプローラで「NODE_F401RE」というドライブが見つかります。

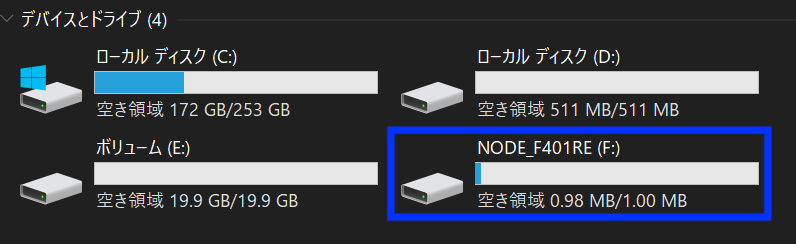
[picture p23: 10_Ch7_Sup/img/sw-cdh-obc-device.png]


これに、先程エクスプローラで表示させた`01_CDH_OBC.bin`をドラッグ&ドロップします。成功すると、OBC上部のLEDが赤と緑で数秒間点滅します。

## 動作確認

[sw-terminal.md](sw-terminal.md)を参考に、Tera TermでMain OBCに接続します。

接続後、Tera Termで文字出力が確認できれば成功です。たとえば、Main OBCがT系OBCに接続されていない場合は以下が継続的に出力されます:

```text
[ERR] transact: failed: cmd=0x10 ret=1
[ERR] comm.handshake: timeout
[ERR] transact: failed: cmd=0x10 ret=1
[ERR] comm.handshake: timeout
[ERR] transact: failed: cmd=0x10 ret=1
[ERR] comm.handshake: timeout
```

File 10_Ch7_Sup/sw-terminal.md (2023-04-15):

# 開発環境準備（ソフトウェア）: ターミナル

本文書は、OBCと有線で通信してログを取得するためのターミナルソフトであるTera Termの準備を行います。

## インストール

[https://osdn.net/projects/ttssh2/releases/](https://osdn.net/projects/ttssh2/releases/) にアクセスします。

ページ中の`teraterm-4.106.exe`をクリックし、インストーラをダウンロードします。

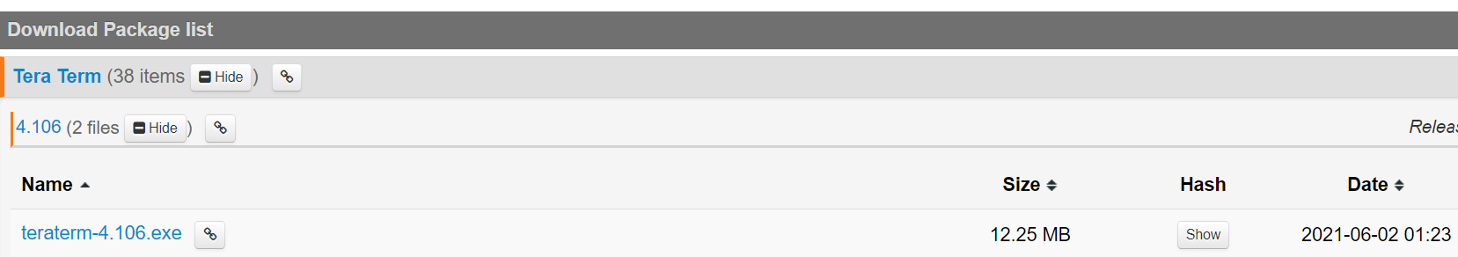
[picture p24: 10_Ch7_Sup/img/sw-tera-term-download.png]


指示に従ってインストールを行います。

## 操作

（OBCへのバイナリ書き込みが完了してから参照ください）

### OBCのポート番号の取得

Tera Termを実行する前に、OBCの「ポート番号」を取得するための作業を行います。

OBCとPCが未接続の状態で、デバイスマネージャーを開きます。

「スタート」（Windowsマーク）をクリックし、そのまま半角入力モードで「device」と入力します。すると、下図のように「デバイス マネージャー」が現れるので、それをクリックして開きます。



「ポート（COMとLPT）」をダブルクリックして展開すると、以下のようにいくつかの項目が現れます（個数は環境によって異なります）。



このまま、OBCとPCをUSBケーブルで接続します。すると画面がリフレッシュされ、下図のように「ポート（COMとLPT）」にデバイスが1個追加されます。この追加されたデバイスのID「COM3」（番号は環境によって異なる）を覚えておきます。



### Tera Termの実行

デバイスマネージャーを閉じ、続けてTera Termを開きます。すると「Tera Term: 新しい接続」というウィンドウが同時に開きます。ここで「シリアル」を選択し、「ポート」に先程のID（上図の場合「COM3」）を選択します。選択後、OKを押します。



続けて、メニューバーの「設定」→「シリアルポート」をクリックし、ポートの設定画面を開きます。



「スピード」に半角で115200を入力し、「現在の接続を再設定」をクリックします。



これで、OBCとの通信が可能になります。

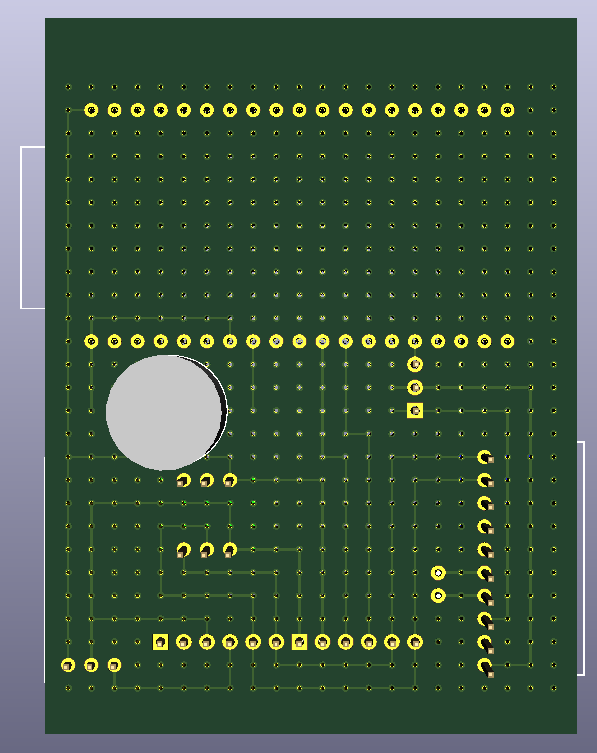
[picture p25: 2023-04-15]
05_Schematic/esp32/2_bot.png

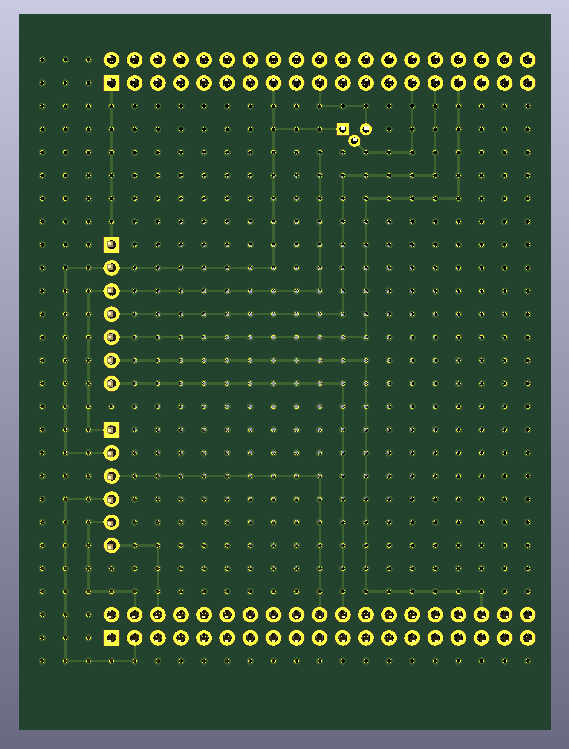
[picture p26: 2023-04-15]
05_Schematic/stm32/1_bot.png

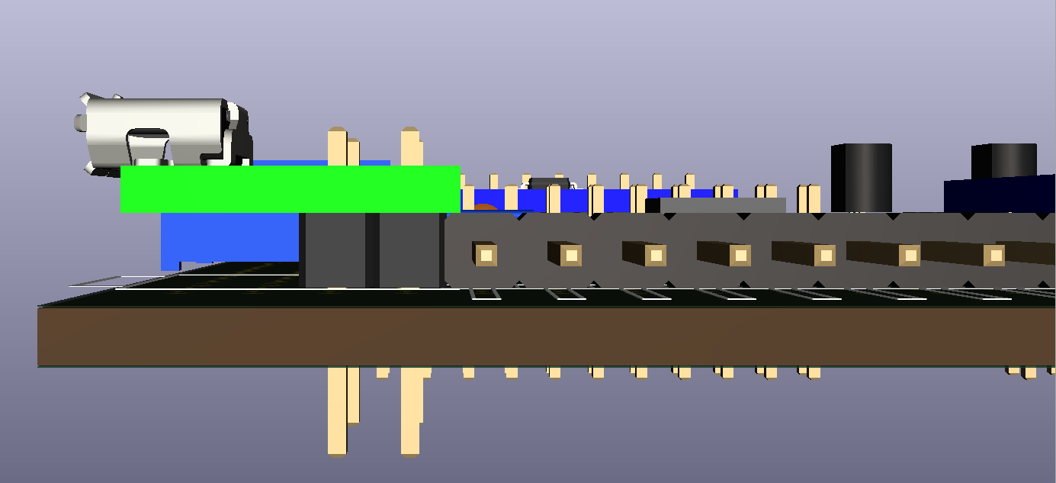
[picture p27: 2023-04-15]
05_Schematic/RaspberryPi/USB1.png

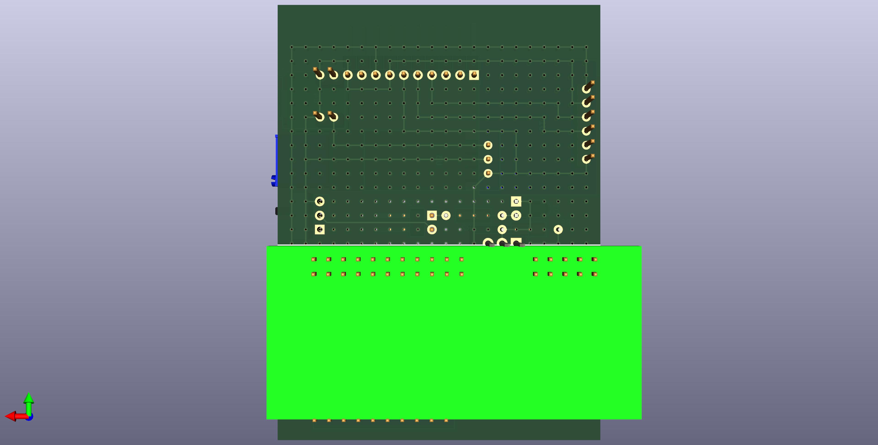
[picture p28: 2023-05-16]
05_Schematic/RaspberryPi/3_bot.jpg

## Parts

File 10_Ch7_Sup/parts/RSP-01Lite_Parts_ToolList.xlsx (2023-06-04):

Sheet: 使用予定部材
使用部材 |  | 2023-05-06 |  |  |  | ¥20262
NO | カテゴリ | 用途 | メーカー | 部品名 | 用途 | 金額(1個） | 個数 | 備考 | 購入場所 | URL | 代替購入URL | I2Cアドレス
1 | C&DH系 | 温度センサ | Texas Instruments | LM61CIZ | 温度測定用 | ¥60 | 1 |  | 秋月電子 | https://akizukidenshi.com/catalog/g/gI-11160/ | https://www.marutsu.co.jp/pc/i/13078170/
2 | C&DH系 | 9軸センサ | BOSCH | BMX055 | 角速度、加速度センサ | ¥1680 | 1 | JP4,JP5をショートしSCL,SDAをプルアップする。 JP7をショートしVCC,I2Cを3V3にする | 秋月電子 | http://akizukidenshi.com/catalog/g/gK-13010/ |  | 0x19,0x69,0x13
3 | C&DH系 | MainOBC | Nucleo | STM32F401 | MainOBC | ¥2800 | 1 |  | 秋月電子 | http://akizukidenshi.com/catalog/g/gM-07723/
4 | C&DH系 | 電圧電流センサ | adafruit | ＩＮＡ２１９使用電流センサーモジュール（カレントセンサー） | 電流、電圧計測 | ¥1320 | 1 |  | 秋月電子 | http://akizukidenshi.com/catalog/g/gM-08221/ |  | 0x40
5 | C系、M系 | DRV8830用コンデンサ | muRata | 0.1μF50V2.54mm | ノイズ除去用 | ¥100 | 1 | 10個入り DRV8830VCC,GND間で使用 | 秋月電子 | https://akizukidenshi.com/catalog/g/gP-00090/
6 | C系、M系 | DRV8830用コンデンサ | muRata | 10μF50V5mm | ノイズ除去用 | ¥50 | 2 | DRV8830VCC,GND間で使用 | 秋月電子 | https://akizukidenshi.com/catalog/g/gP-08155/
7 | M系 | アーム用モータードライバ | Texas Instruments | DRV8830 | カメラアームモーター駆動用 | ¥250 | 1 |  | 秋月電子 | http://akizukidenshi.com/catalog/g/gK-06273/ |  | 0xC8,0xC9,(0x64)
8 | M系 | Mission OBC | Raspberry | Raspberry PI ZeroWH | Mission OBC | ¥2480 | 1 |  | 秋月電子 | http://akizukidenshi.com/catalog/g/gM-12961/
9 | M系 | Raspberry PI ZeroWH用カメラ V1.3 | Raspberry | V1.3 | 魚眼でなく通常品 | ¥880 | 1 |  | Amazon | https://www.amazon.co.jp/dp/B01D1D0DJ0/ | https://www.amazon.co.jp/dp/B01LY05LOE
10 | M系 | MicroSDカード 16GB | HIDISC | HDMCSDH16GCL10UIJP3 | RaspberryPIイメージ書き込み用 | ¥1380 | 1 | microSD 16GBなら何でもよい | 千石電商 | https://www.sengoku.co.jp/mod/sgk_cart/detail.php?code=EEHD-55CS
11 | A系 | リアクションホイール用モータードライバ | Texas Instruments | DRV8830 | リアクションホイールモーター駆動用 | ¥250 | 1 |  | 秋月電子 | http://akizukidenshi.com/catalog/g/gK-06273/ |  | 0xC6,0xC7,(0x63)
12 | A系 | リアクションホイールモーター | タミヤ | ソーラーモーター03 |  | ¥528 | 1 |  | タミヤ | https://tamiyashop.jp/shop/g/g76011/
13 | A系 | リアクションホール | タミヤ | プーリー（L）セット | ホイールとして使用 | ¥462 | 1 | 50㎜プーリーをモーターに取り付け回転させる | タミヤ | https://www.tamiya.com/japan/products/70141/index.html
14 | T系 | Bluetoothモジュール | Espressif Systems (Shanghai) Pte. Ltd. | ESP32 DevkitC |  | ¥1600 | 1 |  | 秋月電子 | http://akizukidenshi.com/catalog/g/gM-11819/
15 | T系 | ブザー | DB Products Limited. | ＵＤＢ－０５ＬＦＰＮ | モールス受信模擬 | ¥80 | 1 |  | 秋月電子 | http://akizukidenshi.com/catalog/g/gP-09704/
16 | P系 | バッテリー | Panasonic | 単四エネループ | バッテリー |  | 3 | 単4エネループ | Panasonic | https://panasonic.jp/battery/products/charge/eneloop.html
17 | P系 | バッテリーボックス | COMF | 電池ボックス 単４×３本 リード線 |  | ¥60 | 1 | 単四ｘ３ | 秋月電子 | https://akizukidenshi.com/catalog/g/gP-03195/
18 | P系 | DC-DCコンバータ | 秋月電子 | AE-LXDC55-ADJ | 5V→4.2V生成 | ¥500 | 1 | USBから充電電圧生成 | 秋月電子 | http://akizukidenshi.com/catalog/g/gK-09982/
19 | P系 | DC-DCコンバータ | 秋月電子 | AE-LXDC55-3.3V | 4.2V→3.3V生成 | ¥450 | 1 | バッテリーからバス電圧生成 | 秋月電子 | http://akizukidenshi.com/catalog/g/gK-09980/
20 | P系 | USB充電コネクタ | 秋月電子 | AE-MRUSB-DIP | USB充電 | ¥130 | 1 |  | 秋月電子 | http://akizukidenshi.com/catalog/g/gK-10972/
21 | P系 | 理想ダイオード用抵抗 | SHIH HAO Electronics CO.,LTD | 10KΩ | 理想ダイオード、MOSFET | ¥100 | 1 | 100本入り 3本使用 | 秋月電子 | https://akizukidenshi.com/catalog/g/gR-25103/
22 | P系 | モータードライバ用抵抗 | ローム | MCR25JZHFLR240 | モータドライバ | ¥100 | 1 | 10個入り 1個使用 チップ抵抗3225 0.24Ω | 秋月電子 | https://akizukidenshi.com/catalog/g/gR-10823/ | https://www.marutsu.co.jp/pc/i/2655053/
23 | P系 | LED用抵抗 | FAITHFUL LINK INDUSTRIAL CORP. | 330Ω | LED用 | ¥100 | 1 | 100本入り 1本使用 | 秋月電子 | https://akizukidenshi.com/catalog/g/gR-25331/
24 | P系 | 理想ダイオードパーツ | Diodes Incorporated. | DMG3415U | 理想ダイオード | ¥300 | 1 | PchMOSFET 10個入 | 秋月電子 | https://akizukidenshi.com/catalog/g/gI-03942/
25 | P系 | 理想ダイオードパーツ | UNISONIC TECHNOLOGIES CO.,LTD | 2N5401L-B-T92-K | 理想ダイオード | ¥10 | 2 | トランジスタ | 秋月電子 | https://akizukidenshi.com/catalog/g/gI-11725/
26 | P系 | バッテリー用GNDスライドスイッチ | Switronic lndustrial Corp. | ＳＳ１２Ｄ０１Ｇ４ | バッテリー用GNDスライドスイッチ | ¥25 | 1 |  | 秋月電子 | https://akizukidenshi.com/catalog/g/gP-12723/
27 | P系 | 通電確認LED | OptoSupply | ＯＳＲ５ＪＡ３Ｚ７４Ａ | バッテリーLED | ¥10 | 1 |  | 秋月電子 | https://akizukidenshi.com/catalog/g/gI-11577/
28 | H系 | ハーネス用ピンヘッダ | Useconn Electronics Ltd. | ピンヘッダ(L型)1x10(10P) | L字アングル | ¥15 | 8 | １×１０ （１０Ｐ） | 秋月電子 | https://akizukidenshi.com/catalog/g/gC-12986/
29 | H系 | モジュール用ピンヘッダ | Useconn Electronics Ltd. | 分割ロングピンソケット １×４２ （４２Ｐ） | STM32用 | ¥80 | 2 | 分割ロングピンソケット １×４２ （４２Ｐ） | 秋月電子 | https://akizukidenshi.com/catalog/g/gC-05779/
30 | H系 | 自撮りアーム | タミヤ | ユニバーサルアームセット No.143 |  | ¥462 | 2 |  | タミヤ | https://www.tamiya.com/japan/products/70143/index.html
31 | H系 | 自撮りアーム | タミヤ | ユニバーサルギアボックス FA-130付き No.103 |  | ¥726 | 1 |  | タミヤ | https://www.tamiya.com/japan/products/70103/index.html
32 | H系 | 自撮りアーム | タミヤ | 3mmネジセット （60､100ｍｍ）No.180 |  | ¥330 | 1 |  | タミヤ | https://www.tamiya.com/japan/products/70180/index.html
33 | H系 | 自撮りアーム | タミヤ | ユニバーサルプレートL No.172 |  | ¥726 | 1 |  | タミヤ | https://www.tamiya.com/japan/products/70172/index.html
34 | H系 | 自撮りアーム | タミヤ | ユニバーサル金具 4本セット No.164 |  | ¥420 | 1 |  | タミヤ | https://www.tamiya.com/japan/products/70164/index.html
35 | H系 | 筐体用ネジ | - | M2.6x5 | 筐体、基板組付け | ¥16 | 6 | 上段STM基板、背面ESP32基板ねじ止め用 | 千石電商 | https://www.sengoku.co.jp/mod/sgk_cart/detail.php?code=3A54-6BJ5
36 | H系 | カメラ固定ナット | - | M2 | カメラ、アーム取り付け | ¥11 | 1 | 10個～注文可能 | 千石電商 | https://www.sengoku.co.jp/mod/sgk_cart/detail.php?code=8A54-7BH8
37 | H系 | カメラ固定ネジ | - | M2x10 | カメラ、アーム取り付け | ¥16 | 1 | 10個～注文可能 | 千石電商 | https://www.sengoku.co.jp/mod/sgk_cart/detail.php?code=3A34-7PH7
38 | H系 | カメラ固定ワッシャー | - | M2ワッシャー | カメラ、アーム取り付け | ¥11 | 4 | 10個～注文可能 | 千石電商 | https://www.sengoku.co.jp/mod/sgk_cart/detail.php?code=2AW4-6BHK
39 | H系 | ボリューム抵抗固定ネジ | - | M2x3 | ボリューム抵抗取付用 | ¥16 | 2 | 10個～注文可能 | 千石電商 | https://www.sengoku.co.jp/mod/sgk_cart/detail.php?code=8AX4-6BHB
40 | H系 | アーム、台座固定ネジ | - | M3x35 | アーム、台座固定用 | ¥16 | 2 | 10個～注文可能 | 千石電商 | https://www.sengoku.co.jp/mod/sgk_cart/detail.php?code=4A64-6PHR
41 | H系 | アーム移動確認用スライドボリューム | upertech Electronic Co., Ltd. | SL4515G-B103L15CM | スライドボリューム（２連Ｂ１０ｋΩ） | ¥100 | 1 |  | 秋月電子 | http://akizukidenshi.com/catalog/g/gP-09242/
42 | H系 | ハーネス 基板用 | 協和ハーモネット株式会社 | スズメッキ線（0.6ｍｍ 10ｍ） | 基板での配線 | ¥330 | 1 | すずメッキ線、被服ワイヤー | 秋月電子 | https://akizukidenshi.com/catalog/g/gP-02220/
43 | H系 | ユニバーサル基板 | Shenzhen DJX Elec&Tech Co.,Ltd | 両面スルーホールユニバーサル基板 ６＊８ |  | ¥80 | 3 |  | 秋月電子 | http://akizukidenshi.com/catalog/g/gP-12980/
44 | H系 | スペーサー | 廣杉計器 | M2.6x10 | 筐体、基板組付け | ¥158 | 3 | オスーメス 4本1セット10本使用 | 千石電商 | https://www.sengoku.co.jp/mod/sgk_cart/detail.php?code=EEHD-4YHY
45 | H系 | スペーサー | 廣杉計器 | M2.6x15 | 筐体、基板組付け | ¥179 | 2 | オスーメス 4本1セット8本使用 | 千石電商 | https://www.sengoku.co.jp/mod/sgk_cart/detail.php?code=EEHD-4YHZ
46 | H系 | スペーサー | - | 六角ナットM2.6x0.45 | 筐体、基板組付け | ¥70 | 2 | （１０個入） 12個使用 | 秋月電子 | https://akizukidenshi.com/catalog/g/gP-14371/
47 | H系 | スペーサー | Ｍ・Ｙ・Ｇ | CB26-6 | 基板取付用 | ¥90 | 4 | 垂直取付用ブロック | 秋月電子 | https://akizukidenshi.com/catalog/g/gP-07307/
48 | H系 | バッテリケース、モーター固定バンド | - | 結束バンド150mm幅2ｍｍ | アーム用モーター、バッテリー消す固定 | ¥110 | 1 | 2本使用 | 100円均一
49 | H系 | バッテリー、モーターコネクタ | JST | XHP-2 | バッテリー、モーター用コネクタ | ¥5 | 3 |  | 秋月電子 | https://akizukidenshi.com/catalog/g/gC-12255/
50 | H系 | XHハウジング用コンタクト | JST | SXH-001T-P0.6 | XHハウジング用 | ¥30 | 1 | 10個入り | 秋月電子 | https://akizukidenshi.com/catalog/g/gC-12264/
51 | H系 | ジャンパワイヤ アームリミット計測用、モーターケーブル用 | SUNHOKEY Electronics Co.,Ltd. | コネクタ付ケーブル20㎝ 40Pオスメス |  | ¥180 | 1 | 20本セット | 秋月電子 | https://akizukidenshi.com/catalog/g/gC-17228/
52 | H系 | ハーネス | Cixi Wanjie Electronic Co.,Ltd | ブレッドボード・ジャンパーワイヤ（オス－オス）10cmセット | ブレッドボード配線用 | ¥180 | 1 | 16本セット | 秋月電子 | https://akizukidenshi.com/catalog/g/gC-05371/
53 | H系 | ハーネス | SUNHOKEY Electronics Co.,Ltd. | コネクタ付ケーブル20㎝40Pメスメス | 基板間接続用ジャンパワイヤ | ¥200 | 1 | 40本セット | 秋月電子 | https://akizukidenshi.com/catalog/g/gC-15868/

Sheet: 工具類
 | 開発に必要な工具
No | 機材名称 | 型番 | 必須 | 使用する章 | 入手場所 | 備考 | 入手URL
1 | はんだごて | - | ○ | 全体 |  | はんだ付け
2 | こて台 | - | ○ | 全体 |  | はんだごて置き
3 | はんだ | - | ○ | 全体 |  | はんだ
4 | ニッパー | - | ○ | 全体 |  | プラスチックやケーブルの切断
5 | 直流安定化電源 | - |  |  |  | 電源共有
6 | やすり | - | ○ | アーム制作 |  | プラスチックパーツの研磨
7 | ドライバー | - | ○ | 全体 |  | 筐体組み立て
8 | ラジオペンチ | - |  |  |  | 筐体組み立て
9 | テスター | - | ○ | 全体 |  | 導通確認
10 | マイクロUSBケーブル | - | ○ |  |  | ESP32、Raspberry pi 接続
11 | ミニUSBケーブル | - | ○ |  |  | STM32接続
12 | 金切りばさみ | - |  |  |  | 金属部品切断
13 | 精密圧着ペンチ | PA-20 | ○ |  |  | コンタクトの圧着用
14 | ワイヤストリッパ | - |  |  |  | ワイヤー被覆剥き
15 | ペンチ | - |  |  |  | 部品加工
16 | ピンセット | - |  |  |  | 筐体組み立て
17 | オシロスコープ | - |  |  |  | 信号確認
18
19
20
21
22
23
24
25
26
27
28
29
30
31
32
33
34
35
36
37

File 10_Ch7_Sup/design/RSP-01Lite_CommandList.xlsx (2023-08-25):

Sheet: コマンドリスト
コマンドリスト
ID | 名称 | 概要 | 詳細・補足 | パラメータ |  |  |  |  | 応答
 |  |  |  | 総長 [bytes] | 名称 | 長さ [byte] | 内容 | とりうる値 | 総長 [bytes] | 名称 | 長さ [byte] | 内容 | とりうる値 | 補足
0x01 | COMM_TEST | 各機器の通信テストを行う | Main OBC、Mission OBCを対象にしたエコーテスト。 | 1 | target | 1 | テストの対象 | 0x01: メインOBC 0x02: Mission OBC | 1 | result | 1 | テストの結果 | 0: 成功 1: 失敗 2: RPiが電源OFFのため失敗 | -
0x11 | GET_HKDATA | 保存されたHKデータを取得する | - | 2 | offset | 1 | 取得開始アドレス（オフセット） | 0-255 | 55 x num | items | 55 | 「HKデータ」シート参照 | - | -
 |  |  |  |  | num | 1 | 取得するHKデータの個数 | 0-255
0x12 | RESET | システムをリセットする | - | 1 | mainobc | 1 | メインOBC | 0x00: リセットしない 0x01: リセットする | 0 | - | - | - | - | -
0x20 | POWER | 指定されたコンポーネントの電源を制御する | - | 2 | target | 1 | 操作対象 | 0x00: RPi | 1 | result | 1 | 実行結果 | 0x00: 成功 0x01: 失敗 | -
 |  |  |  |  | state | 1 | 操作後の電源状態 | 0x00: OFF 0x01: ON
0x31 | DRIVE_ARM | アームの展開・収納を行う | - | 1 | mode | 1 | 動作モード | 0x00: 展開 0x01: 収納 0x10: 強制展開（時間指定） 0x11: 強制収納（時間指定） 0x20: 展開・撮影・収納 | 6 | result_exp | 1 | 展開成否 | 0x00: 成功 それ以外: 失敗（補足列を参照） | bit[2 - 7]はエラーの原因を表す。 bit[2]: ILIMIT: If set, indicates the fault was caused by an extended current limit event bit[3]: OTS: If set, indicates that the fault was caused by an overtemperature (OTS) condition bit[4]: UVLO: If set, indicates the fault was caused by an undervoltage lockout bit[5]: OCP: If set, indicates the fault was caused by an overcurrent (OCP) event bit[6]: 1がセットされている場合、アームのスライドボリュームが異常値を返している。 bit[7]: 1がセットされている場合、DRV8830からI2C通信のレスポンスが無い。
 |  |  |  |  |  |  |  |  |  | result_fold | 1 | 収納成否 | 0x00: 成功 それ以外: 失敗（補足列を参照）
 |  |  |  |  |  |  |  |  |  | pos | 2 | コマンド終了後のアームの位置 | リニアボリュームの分圧値が10bitで設定される。 | -
 |  |  |  |  |  |  |  |  |  | result_comm | 1 | RPiとの通信成否 | 0x00: 成功 それ以外: 失敗 | -
 |  |  |  |  |  |  |  |  |  | result_pic | 1 | 撮影実行成否 | 0x00: 成功 それ以外: 失敗 | -
0x33 | TAKE_PIC | 画像の撮影を実行する | ・1秒間隔で10秒間の撮影を10分後に行う場合のパラメータ例は、0x03E8（1秒）、0x2710（10秒間）、0x0927C0（10分） | 7 | interval | 2 | 撮影間隔 [ms] | 0x0000 - 0xFFFF | 1 | result | 1 | 撮影の成否 | 0x00: 成功 0x01: 失敗
 |  |  |  |  | duration | 2 | 撮影時間 [ms] | 0x0000 - 0xFFFF
 |  |  |  |  | start | 3 | タイマー [ms] | 0x000000 - 0xFFFFFF
0x34 | GET_PIC_LIST | 画像IDリストの取得 | - | 4 | start | 2 | 取得開始ID | 0x0000 - 0xFFFF | 4 x (end - start + 1) + 2 | result | 1 | 画像IDリストの取得の成否 | 0x00: 成功 0x01: 失敗 | -
 |  |  |  |  | end | 2 | 取得終了ID | 0x0000 - 0xFFFF |  | count | 1 | 取得画像IDリストの要素数 | 0x00 - 0xFF | -
 |  |  |  |  |  |  |  |  |  | list[0] | 4 | ID(<start>) | 0x00000000 - 0xFFFFFFFF | 引数で指定した範囲の画像IDを返す。 上位2byteをid、下位2byteをsub_idとする。 sub_idがなしの場合は0xffffを下位2byteに指定する。
 |  |  |  |  |  |  |  |  |  | list[1] | 4 | ID(<start>+1) | 0x00000000 - 0xFFFFFFFF | -
 |  |  |  |  |  |  |  |  |  | list[N] | 4 | ID(<end>) | 0x00000000 - 0xFFFFFFFF | -
0x35 | GET_PIC_INFO | 画像情報の取得 | - | 5 | start | 2 | 取得開始ID | 0x0000 - 0xFFFF | 13 x (end - start + 1) + 2 | result | 1 | 画像情報取得の成否 | 0x00: 成功 0x01: 失敗 | -
 |  |  |  |  | end | 2 | 取得終了ID | 0x0000 - 0xFFFF |  | count | 1 | 取得した画像情報の数 | 0～255 | 引数で指定された範囲のIDの画像情報を返す。
 |  |  |  |  | type | 1 | 画像の種類 | 0x00: 縮小画像 0x01: オリジナル画像 |  | items | 13 | Picinfo(<start>) | 「Picinfoデータ」シート参照。 | -
 |  |  |  |  |  |  |  |  |  | items | 13 | Picinfo(<start>+1)
 |  |  |  |  |  |  |  |  |  | items | 13 | Picinfo(<end>)
0x36 | GET_PIC_DATA | 画像データの取得 | - | 11 | type | 1 | 画像の種類 | 0x00: 縮小画像 0x01: オリジナル画像 | コマンド依存 | result | 1 | 画像データ取得の成否 | 0x00: 成功 0x01: 失敗 0x02: 画像タイプ指定誤り 0x04: データ切り捨てが発生 0x08: MissionOBCと通信失敗 （ビットにエラーを割り当て） | -
 |  |  |  |  | id | 2 | 画像ID | 0x0000 - 0xFFFF |  | type | 1 | 画像の種類 | 0x00: 縮小画像 0x01: オリジナル画像 | -
 |  |  |  |  | sub_id | 2 | 画像sub ID | 0x0000 - 0xFFFF ただし、0xFFFFは sub_id指定なしとして扱う |  | id | 2 | 画像ID | 0x0000 - 0xFFFF | -
 |  |  |  |  | pos | 3 | 開始アドレス | 0x000000 - 0xFFFFFF |  | subId | 2 | 画像sub ID | 0x0000 - 0xFFFF ただし、0xFFFFは sub_id指定なしとして扱う | -
 |  |  |  |  | size | 3 | 取得バイト数 | 0x000000 - 0xFFFFFF |  | pos | 3 | アドレスオフセット | 0x000000 - 0xFFFFFF | -
 |  |  |  |  |  |  |  |  |  | data | N | 画像のバイナリデータ | （バイナリ） | -
0x38 | DELETE_PIC | 画像の削除 | - | 5 | id | 2 | 画像のID | 0x0000 - 0xFFFF | 1 | result | 1 | 画像削除の成否 | 0x00: 成功 0x01: 失敗 | -
 |  |  |  |  | sub_id | 2 | 画像のsub ID | 0x0000 - 0xFFFF ただし、0xFFFFは sub_id指定なしとして扱う
 |  |  |  |  | type | 1 | 画像の種類 | 0x00: オリジナル画像 0x01: 縮小画像 0x02: 両方
0x39 | SET_PIC_SIZE | 画像サイズの設定 | - | 5 | mode | 1 | 画像の種類 | 0x00: オリジナル画像 0x01: 縮小画像 | 1 | - | 1 | 処理の成否 | 0x00: 成功 0x01: 失敗 | -
 |  |  |  |  | width | 2 | 画像の幅 [px] | 0x0028 - 0x0A20(40 ~ 2592)
 |  |  |  |  | height | 2 | 画像の高さ [px] | 0x0028 - 0x0798(40 ~ 1944)
0x3C | GET_CAM_CONFIG | カメラ設定の取得 | - | 0 | (none) | 0 | (none) | (none) | 11 | iso | 2 | カメラのISO | 0x0064 - 0x0320(100 ~ 800) | -
 |  |  |  |  |  |  |  |  |  | shutter | 3 | シャッター速度 | 0x0000 - 0x5b8d80(0 ~ 6000000us) | -
 |  |  |  |  |  |  |  |  |  | quality | 1 | JPEG品質 | 0x00 - 0x64(0 ~ 100) | -
 |  |  |  |  |  |  |  |  |  | sharpness | 1 | シャープネス | 0x9C - 0x64(-100 ~ 100) | -
 |  |  |  |  |  |  |  |  |  | contrast | 1 | コントラスト | 0x9C - 0x64(-100 ~ 100) | -
 |  |  |  |  |  |  |  |  |  | brightness | 1 | 明るさ | 0x00 - 0x64(0 ~ 100) | -
 |  |  |  |  |  |  |  |  |  | saturation | 1 | 彩度 | 0x9C - 0x64(-100 ~ 100) | -
 |  |  |  |  |  |  |  |  |  | exposure | 1 | 露出 | 0x00 - 0xFF 0x00: off 0x01: auto 0x02: night 0x03: nightpreview 0x04: backlight 0x05: spotlight 0x06: sports 0x07: snow 0x08: beach 0x09: verylong 0x0a: fixedfps 0x0b: antishake 0x0c: fireworks | -
0x3D | SET_CAM_CONFIG | カメラ設定の設定 | - | 11 | iso | 2 | カメラのISO | 0x0064 - 0x0320(100 ~ 800) | 1 | result | 1 | 通信成否 | 0x00: 成功 0x01: 失敗 | -
 |  |  |  |  | shutter | 3 | シャッター速度 [μs] | 0x0000 - 0x5b8d80(0 ~ 6000000us)
 |  |  |  |  | quality | 1 | JPEG品質 | 0x00 - 0x64(0 ~ 100)
 |  |  |  |  | sharpness | 1 | シャープネス | 0x9C - 0x64(-100 ~ 100)
 |  |  |  |  | contrast | 1 | コントラスト | 0x9C - 0x64(-100 ~ 100)
 |  |  |  |  | brightness | 1 | 明るさ | 0x00 - 0x64(0 ~ 100)
 |  |  |  |  | saturation | 1 | 彩度 | 0x9C - 0x64(-100 ~ 100)
 |  |  |  |  | exposure | 1 | 露出 | 0x00 - 0xFF 0x00: off 0x01: auto 0x02: night 0x03: nightpreview 0x04: backlight 0x05: spotlight 0x06: sports 0x07: snow 0x08: beach 0x09: verylong 0x0a: fixedfps 0x0b: antishake 0x0c: fireworks
0x3E | UPLINK_FILE | 地上からRPiへファイルを送信する | - | 25+[size] | pos | 3 | 開始アドレス | 0x000000 - 0xFFFFFF | 1 | result | 1 | 通信成否 | 0x00: 成功 0x01: 失敗 | -
 |  |  |  |  | size | 2 | データサイズ | 0x0000 - 0xFFFF
 |  |  |  |  | filename | 20 | ファイル名（格納先はRPiの固定ディレクトリ） | 0x00...0 - 0xFF...F
 |  |  |  |  | data | [size] | データ | （データごとに異なる）
0x3F | DOWNLINK_FILE | 指定されたファイルを地上がRasPiから取得する。 | - | 7+[size] | pos | 3 | 開始アドレス | 0x000000 - 0xFFFFFF | 1+N | result | 1 | データ取得の成否 | 0x00: 成功 0x01: 失敗 | -
 |  |  |  |  | size | 2 | データサイズ | 0x0000 - 0xFFFF |  | data | N | 取得したデータ | （バイナリ） | -
 |  |  |  |  | filepath_size | 2 | ファイルの絶対パスのサイズ | 0x0000 - 0xFFFF
 |  |  |  |  | filepath | [size] | ファイルの絶対パス | （データごとに異なる）
0x41 | START_PIC_CATEG | 画像分類開始 | - | 1 | work_type | (2bit) | 使用するライブラリ | 0x1: TensorFlow Lite ('tfl') 0x0: TensorFlow ('tf') | 2 | exe_result | 1 | コマンド実行結果 | 10: 成功 11: 不明なコマンド名 12: 不明なエラー 13: コマンドエラー 14: 引数不正 15: 正常に終了してない（もしくは処理中） 16: root.log が見つからない 17: root.log parse 失敗 18: cmd.log が見つからない 19: cmd.log parse 失敗 20: 処理開始 | -
 |  |  |  |  | is_all | (2bit) | 全て分類し直すかどうか | 0x1: 全て分類し直す (true) 0x0: 続きから分類する (false) |  | cmd_result | 1 | コマンド処理結果 | 0: Good 1: Bad 19: log のフォーマットが想定外 20: 処理開始 21: 異常終了 22: 正常終了 119: log のフォーマットが想定外（log の時刻が１時間以上前） 201: コマンドの実行まで処理が進んでいない 218: log ファイルが見つからない 219: log の分割に失敗 220: 不正なコード値（数値以外） 221: 不正なコード値（0 - 255 の範囲外） 223: log の日付のフォーマットが不正 | -
 |  |  |  |  | do_wait | (2bit) | 分類が終わるのを待つかどうか | 0x1: 待つ (true) 0x0: 待たない (false)
0x42 | CHECK_PIC_CATEG | 画像分類状況確認 | - | 0 | (none) | 0 | (none) | (none) | 2 | exe_result | 1 | コマンド実行結果 | 10: 成功 11: 不明なコマンド名 12: 不明なエラー 13: コマンドエラー 14: 引数不正 15: 正常に終了してない（もしくは処理中） 16: root.log が見つからない 17: root.log parse 失敗 18: cmd.log が見つからない 19: cmd.log parse 失敗 20: 処理開始 | -
 |  |  |  |  |  |  |  |  |  | cmd_result | 1 | コマンド処理結果 | 0: Good 1: Bad 19: log のフォーマットが想定外 20: 処理開始 30: 処理中 31: 停止 32: 停止受付済 33: 異常停止 119: log のフォーマットが想定外（log の時刻が１時間以上前） 201: コマンドの実行まで処理が進んでいない 218: log ファイルが見つからない 219: log の分割に失敗 220: 不正なコード値（数値以外） 221: 不正なコード値（0 - 255 の範囲外） 223: log の日付のフォーマットが不正 | -
0x43 | ABORT_PIC_CATEG | 画像分類強制終了 | - | 0 | (none) | 0 | (none) | (none) | 2 | exe_result | 1 | コマンド実行結果 | 10: 成功 11: 不明なコマンド名 12: 不明なエラー 13: コマンドエラー 14: 引数不正 15: 正常に終了してない（もしくは処理中） 16: root.log が見つからない 17: root.log parse 失敗 18: cmd.log が見つからない 19: cmd.log parse 失敗 20: 処理開始 | -
 |  |  |  |  |  |  |  |  |  | cmd_result | 1 | コマンド処理結果 | 0: Good 1: Bad 19: log のフォーマットが想定外 20: 処理開始 40: 停止成功 41: 停止失敗 119: log のフォーマットが想定外（log の時刻が１時間以上前） 201: コマンドの実行まで処理が進んでいない 218: log ファイルが見つからない 219: log の分割に失敗 220: 不正なコード値（数値以外） 221: 不正なコード値（0 - 255 の範囲外） 223: log の日付のフォーマットが不正 | -
0x44 | GET_PIC_CATEG | 画像分類情報の取得 | withoutTFは対象の画像が未判定の場合、未判定と返す。withTFは判定してから判定を返す。 | 5 | work_type | 1 | 未判定時の挙動の種類 | 0x00: tf 0x01: tfl 0x02: no | 4 | exe_result | 1 | コマンド実行結果 | 10: 成功 11: 不明なコマンド名 12: 不明なエラー 13: コマンドエラー 14: 引数不正 15: 正常に終了してない（もしくは処理中） 16: root.log が見つからない 17: root.log parse 失敗 18: cmd.log が見つからない 19: cmd.log parse 失敗 20: 処理開始 | -
 |  |  |  |  | id | 2 | 画像のID | 0x0000 - 0xFFFF |  | cmd_result | 1 | コマンド処理結果 | 0: Good 1: Bad 19: log のフォーマットが想定外 20: 処理開始 60: 成功 61: 未分類 62: ファイルが存在しない 63: 画像分類エラー 64: work_type エラー 119: log のフォーマットが想定外（log の時刻が１時間以上前） 201: コマンドの実行まで処理が進んでいない 218: log ファイルが見つからない 219: log の分割に失敗 220: 不正なコード値（数値以外） 221: 不正なコード値（0 - 255 の範囲外） 223: log の日付のフォーマットが不正 | -
 |  |  |  |  | sub_id | 2 | 画像のsub ID | 0x0000 - 0xFFFF |  | categ | 1 | 画像の分類 | 0: good 1: bad 61: 画像分類未実施 220: 不正なコード値（数値以外） 221: 不正なコード値（0 - 255 の範囲外） | -
 |  |  |  |  | - |  |  |  |  | percent | 1 | 判定結果の確率 [%] | 0 - 100 | -
0x45 | GET_GOOD_PIC_IDS | 画像分類の結果、good と判定された id を返す | - | 0 | - | - | - | - | 3 + 4 x N | exe_result | 1 | コマンド実行結果 | 10: 成功 11: 不明なコマンド名 12: 不明なエラー 13: コマンドエラー 14: 引数不正 15: 正常に終了してない（もしくは処理中） 16: root.log が見つからない 17: root.log parse 失敗 18: cmd.log が見つからない 19: cmd.log parse 失敗 20: 処理開始 | -
 |  |  |  |  |  |  |  |  |  | cmd_result | 1 | コマンド処理結果 | 0: Good 1: Bad 19: log のフォーマットが想定外 20: 処理開始 50: 成功 51: 失敗 119: log のフォーマットが想定外（log の時刻が１時間以上前） 201: コマンドの実行まで処理が進んでいない 218: log ファイルが見つからない 219: log の分割に失敗 220: 不正なコード値（数値以外） 221: 不正なコード値（0 - 255 の範囲外） 223: log の日付のフォーマットが不正 | -
 |  |  |  |  |  |  |  |  |  | count | 1 | リストの要素数 | 0x00 - 0xFF | -
 |  |  |  |  |  |  |  |  |  | id-subid[0] | 4 | goodなID-subIDの組 | 上位2byteがID、下位2byteがsubID。 | -
 |  |  |  |  |  |  |  |  |  | id-subid[N-1] | 4 | goodなID-subIDの組 | - | -
0x56 | EXEC_SHELL | 任意シェル実行 | - | N | cmd | N | シェルコマンド | （データごとに異なる） | N | msg | N | シェル実行結果 | - | -
0x60 | DRIVE_RWHEEL | リアクションホイールを駆動する | - | 6 | mode | 1 | 動作モード | 0x0: 制御開始 0x1: 制御終了 | 1 | result | 1 | コマンド実行成否 | 0x00: 成功 0x01: 失敗 | -
 |  |  |  |  | target | 2 | 角速度の目標値 [deg/s] | -32768 - 32767
 |  |  |  |  | sec | 3 | 実行時間 [sec] | 0 - 0xFFFFFF
0x61 | CONFIG_RWHEEL | リアクションホイールの制御パラメータを設定する | - | 10 | c_in[0] | 2 | c_in[0] | -32768 - 32767 | 1 | result | 1 | コマンド実行成否 | 0x00: 成功 0x01: 失敗 | -
 |  |  |  |  | c_in[1] | 2 | c_in[1] | -32768 - 32767
 |  |  |  |  | c_in[2] | 2 | c_in[2] | -32768 - 32767
 |  |  |  |  | c_out[1] | 2 | c_out[1] | -32768 - 32767
 |  |  |  |  | c_out[2] | 2 | c_out[2] | -32768 - 32767

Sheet: HKデータ
0x12：GET_HKDATA テレメトリ内容 1個のHKデータは連続したバイト列で、この表中のデータが上から順に格納されています。 値はすべてビッグエンディアンで格納されます。
名称 | 内容 | サイズ[byte] | 開始アドレス [byte] | 詳細
id | このHKデータのID | 2 | 0
current_ms | 衛星起動後からの経過時間 [ms] | 4 | 2
temp | 衛星の温度 [℃] | 4 | 6
power_mw | 消費電力 [mW] | 2 | 10
current_ma | 電流 [mA] | 2 | 12
bus_vol_mv | 電圧 [mV] | 2 | 14
powstat | 各デバイスの電源状態 | 1 | 15 | Bit 0 - 3: RPi
commstat | 各デバイスとメインOBC間の直前の通信状態 | 2 | 16 | 未使用
acc_x | 加速度（x軸） | 4 | 16
acc_y | 加速度（y軸） | 4 | 20
acc_z | 加速度（z軸） | 4 | 24
gyr_x | 角速度（x軸） | 4 | 28
gyr_y | 角速度（y軸） | 4 | 32
gyr_z | 角速度（z軸） | 4 | 36
mag_x | 磁気（x軸） | 4 | 40
mag_y | 磁気（y軸） | 4 | 44
mag_z | 磁気（z軸） | 4 | 48
 | 総計 | 55

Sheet: Picinfoデータ
0x35:GET_PIC_INFO テレメトリ内容
カテゴリ | データ |  |  |  | 詳細
 | 総長 [byte] | 名称 | 長さ[byte] | 内容
Picinfo | 13 | id | 2 | 画像のID | 0x0000 - 0xffff
 |  | sub_id | 2 | 画像IDの枝番 | 0x0000 - 0xffff
 |  | type | 1 | 画像の種類 | 0: 縮小画像 1: オリジナル
 |  | width | 2 | 画像の幅 | 0x0000 - 0xffff
 |  | height | 2 | 画像の高さ | 0x0000 - 0xffff
 |  | size | 3 | 画像のデータサイズ [byte] | 0x000000 - 0xffffff
 |  | categ | 1 | 画像の分類 | 0: bad 1: good 61: 未分類

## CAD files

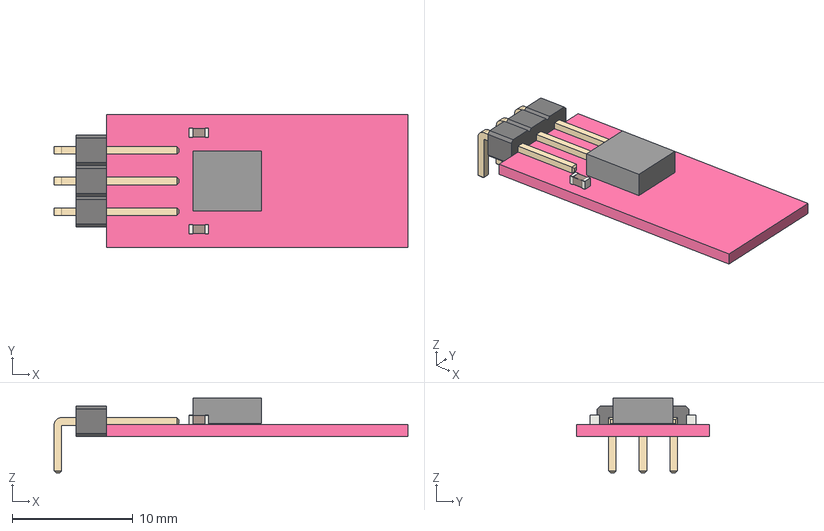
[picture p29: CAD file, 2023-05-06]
05_Schematic/esp32/3d/AE-LXDC55 v7.step
29.4 x 11.0 x 6.20 mm
C_0603_1608Metric x 2
Pins

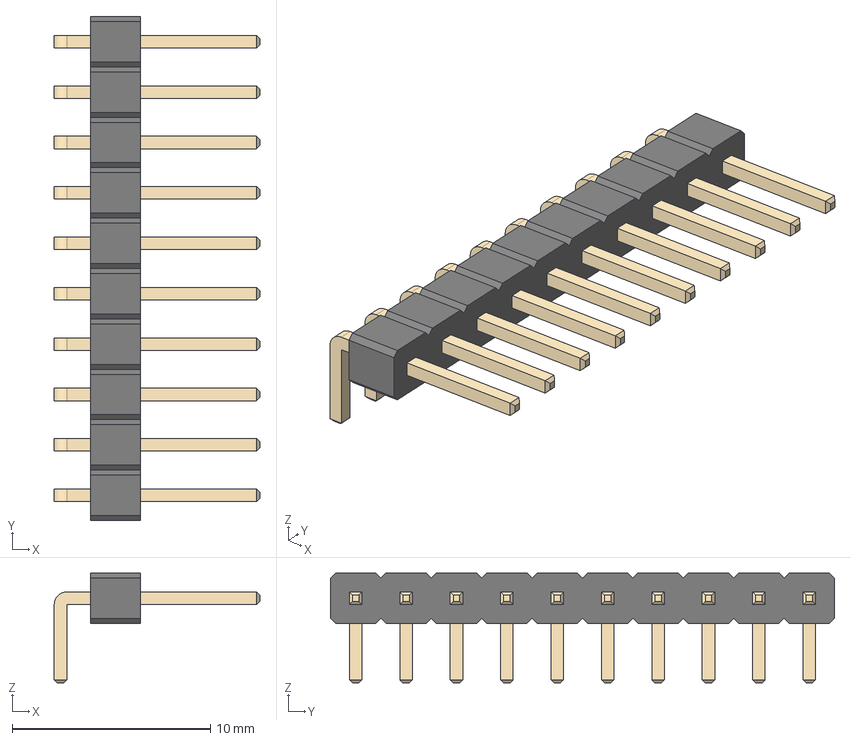
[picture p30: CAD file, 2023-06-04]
05_Schematic/RaspberryPi/3d/PinHeader_1x10_P2.54mm_Horizontal.step
10.4 x 25.4 x 5.54 mm

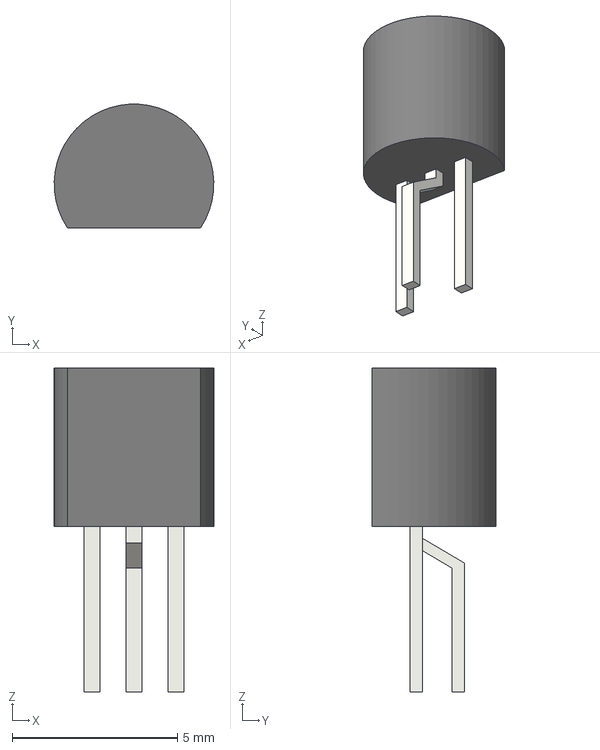
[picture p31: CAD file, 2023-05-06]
05_Schematic/stm32/3d/TO-92.step
4.83 x 3.74 x 9.80 mm

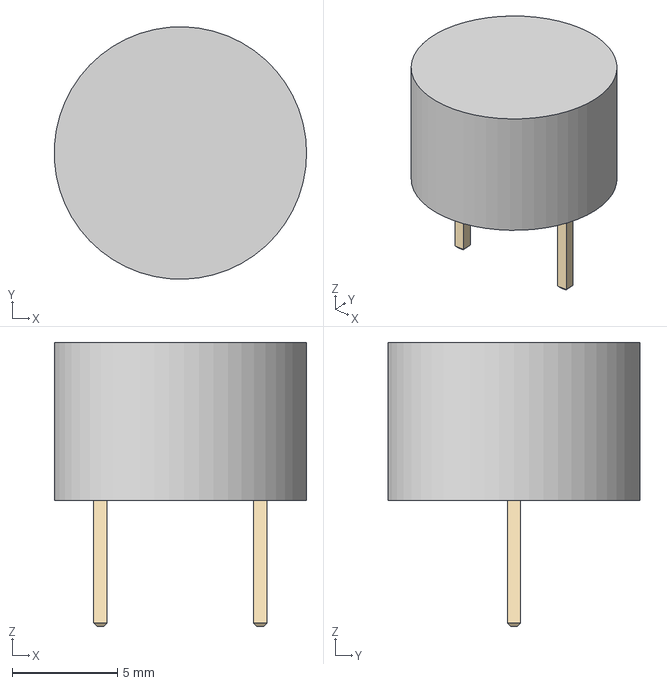
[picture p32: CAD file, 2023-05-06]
05_Schematic/esp32/3d/Buzzer v0.step
12.0 x 12.0 x 13.5 mm

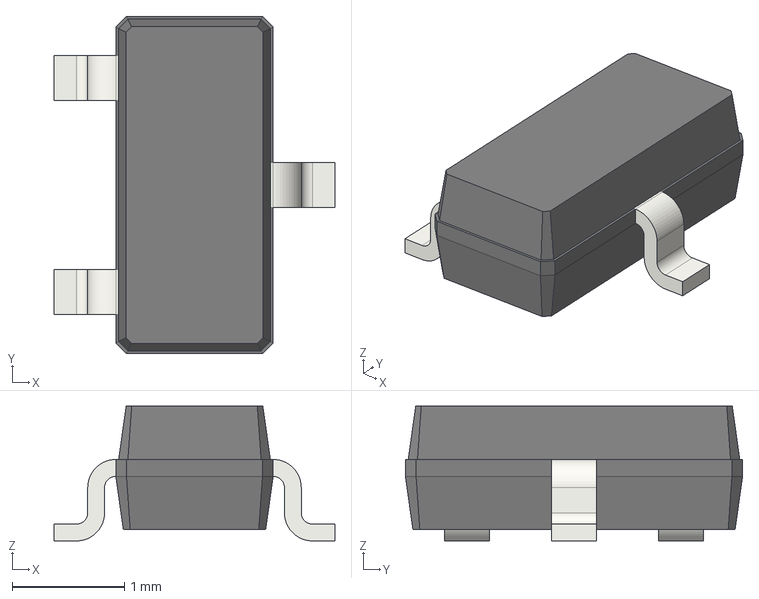
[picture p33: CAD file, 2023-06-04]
05_Schematic/RaspberryPi/3d/SOT-23.step
2.50 x 3.00 x 1.20 mm

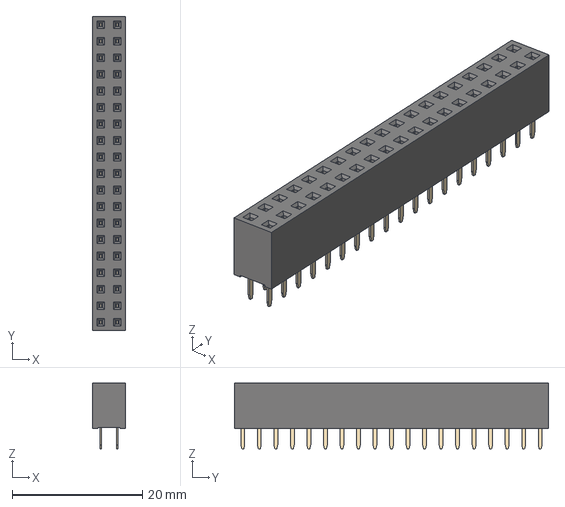
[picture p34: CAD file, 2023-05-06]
05_Schematic/stm32/3d/PinSocket_2x19_P2.54mm_Vertical.step
5.08 x 48.3 x 10.1 mm

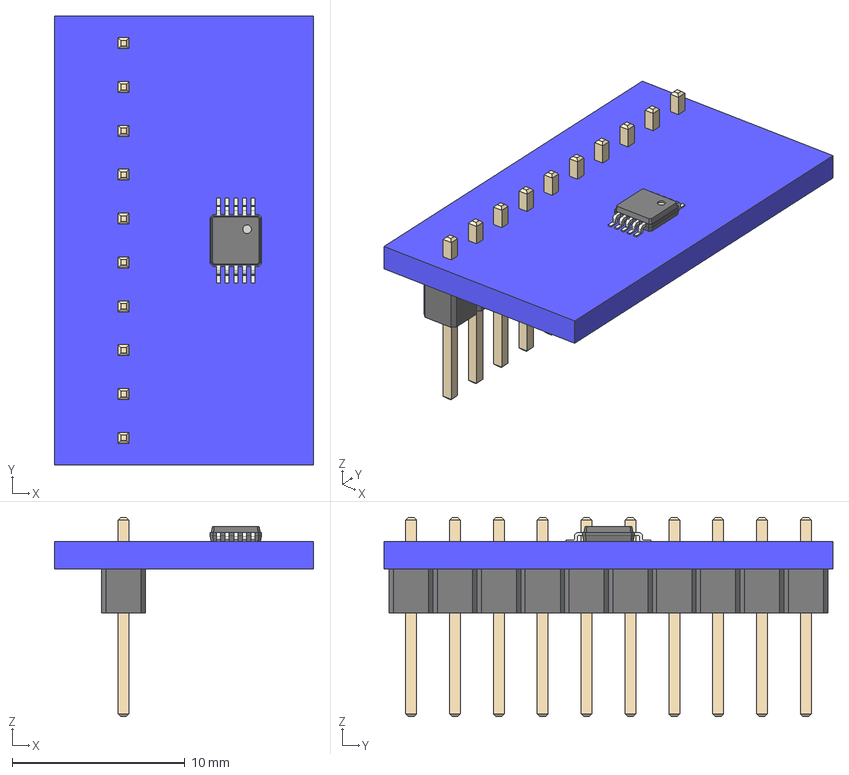
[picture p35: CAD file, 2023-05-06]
05_Schematic/esp32/3d/DRV8830 v2.step
15.0 x 26.0 x 11.5 mm

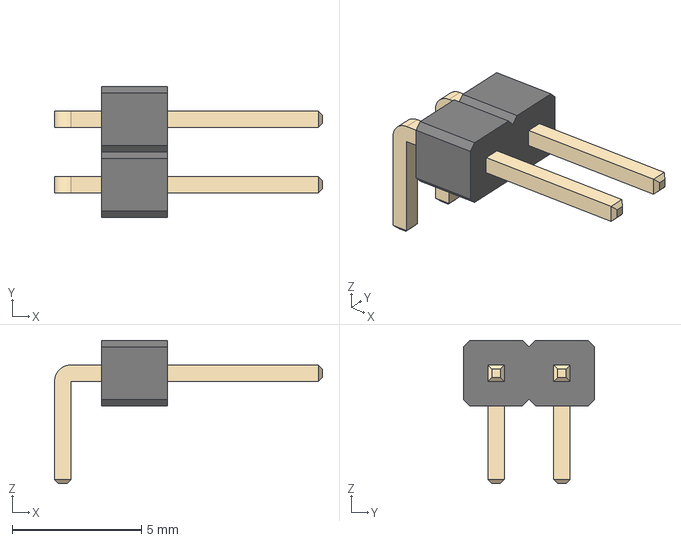
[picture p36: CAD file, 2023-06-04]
05_Schematic/RaspberryPi/3d/PinHeader_1x02_P2.54mm_Horizontal.step
10.4 x 5.08 x 5.54 mm

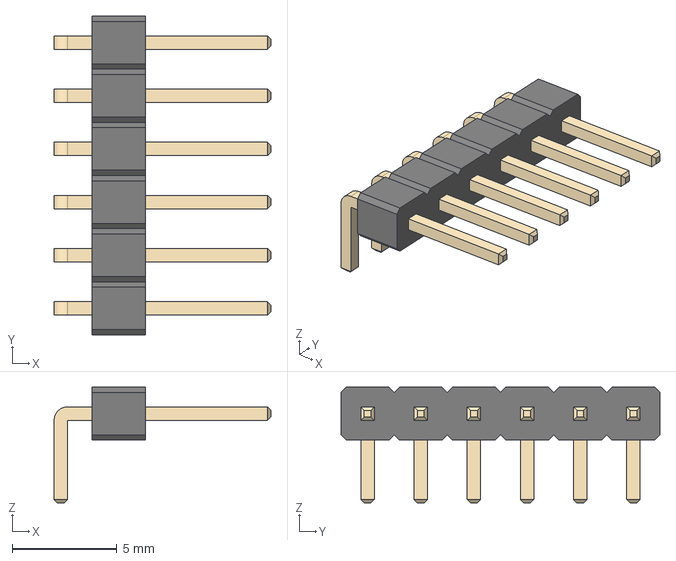
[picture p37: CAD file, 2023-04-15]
05_Schematic/stm32/3d/PinHeader_1x06_P2.54mm_Horizontal.step
10.4 x 15.2 x 5.54 mm

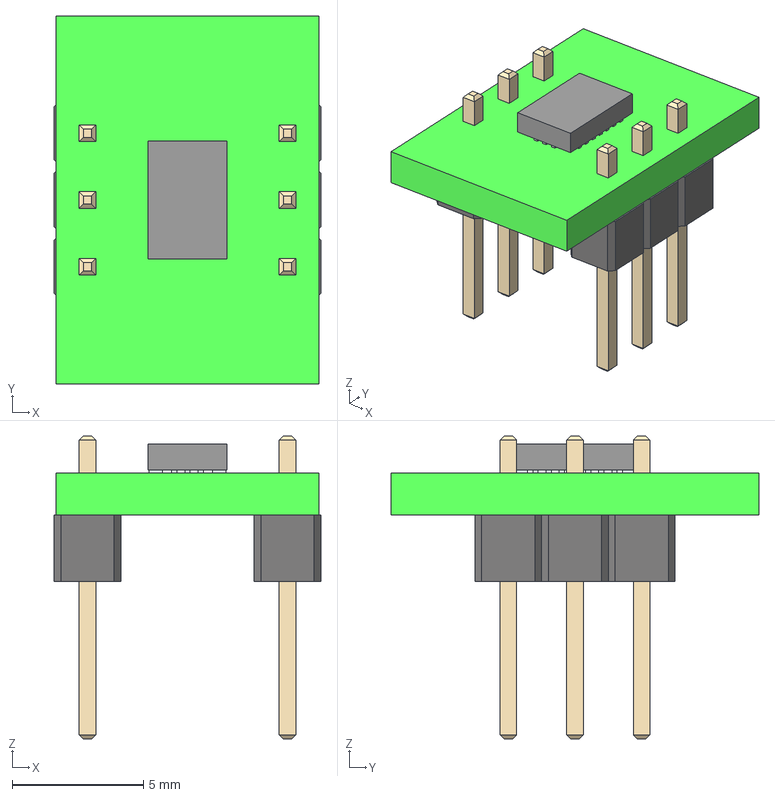
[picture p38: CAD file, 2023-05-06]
05_Schematic/esp32/3d/BMX055 v3.step
10.2 x 14.0 x 11.5 mm
PinHeader_1x03_P2.54mm_Vertical
Pins

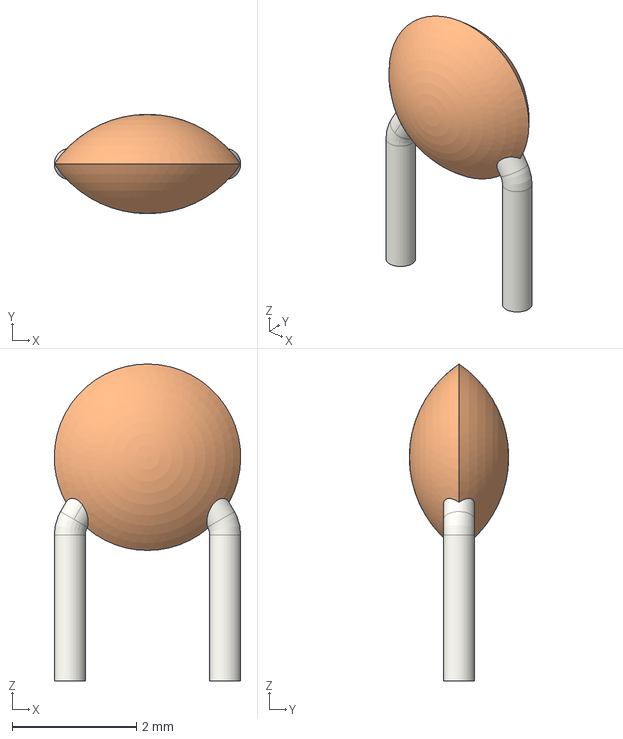
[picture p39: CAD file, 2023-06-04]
05_Schematic/RaspberryPi/3d/C_Disc_D3.0mm_W1.6mm_P2.50mm.step
3.00 x 1.60 x 5.10 mm

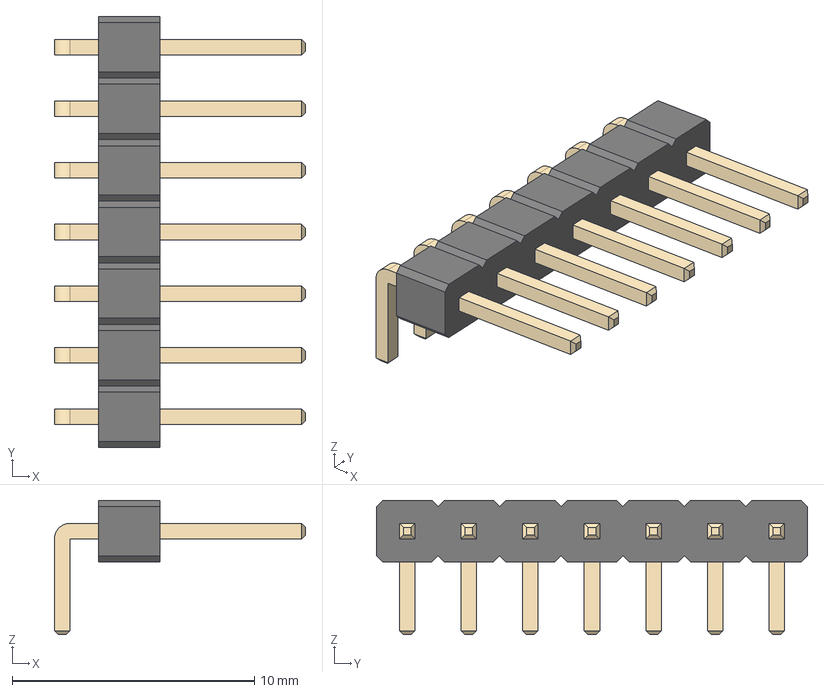
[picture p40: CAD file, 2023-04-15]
05_Schematic/stm32/3d/PinHeader_1x07_P2.54mm_Horizontal.step
10.4 x 17.8 x 5.54 mm

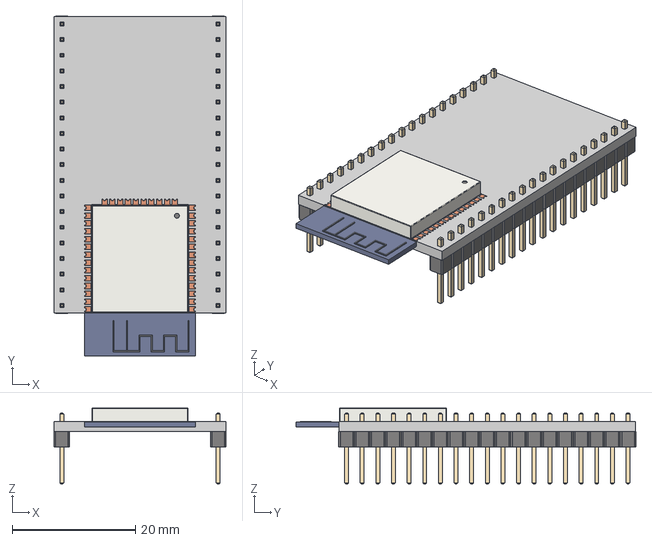
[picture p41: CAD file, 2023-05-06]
05_Schematic/esp32/3d/ESP32 v3.step
27.9 x 55.2 x 12.3 mm
PinHeader_1x19_P2.54mm_Vertical x 2
ESP32-WROOM-32

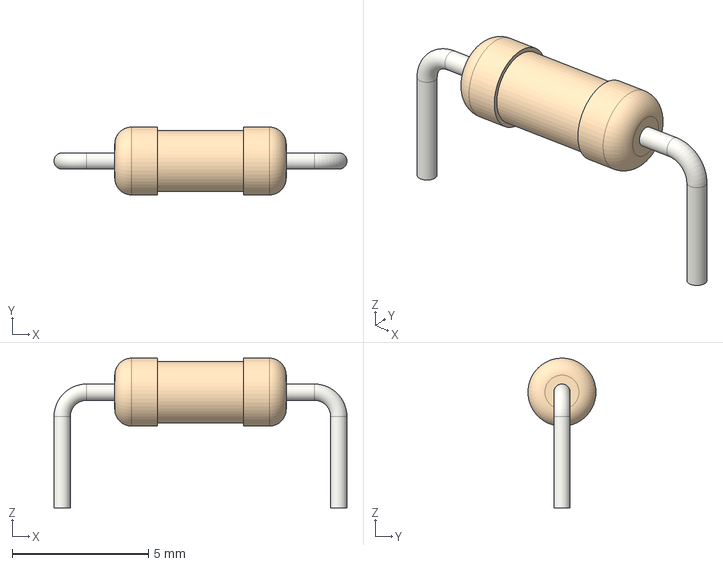
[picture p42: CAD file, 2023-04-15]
05_Schematic/RaspberryPi/3d/R_Axial_DIN0207_L6.3mm_D2.5mm_P10.16mm_Horizontal.step
10.8 x 2.50 x 5.50 mm

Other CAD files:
05_Schematic/esp32/3d/C_Disc_D3.0mm_W1.6mm_P2.50mm.step
05_Schematic/RaspberryPi/3d/INA219 v1.step
05_Schematic/esp32/3d/PinHeader_1x03_P2.54mm_Horizontal.step
05_Schematic/RaspberryPi/3d/User Library-Mini Slide Switch-3Ppin-SPDT-0_3A.STEP
05_Schematic/RaspberryPi/3d/AE-LXDC55-2 v3.step
05_Schematic/RaspberryPi/3d/DRV8830 v2.step
05_Schematic/RaspberryPi/3d/LED_D3.0mm_Horizontal_O1.27mm_Z2.0mm.step
05_Schematic/RaspberryPi/3d/TO-220-3_Vertical.step
05_Schematic/RaspberryPi/3d/TO-92_Inline.step
05_Schematic/RaspberryPi/3d/USB v3.step
05_Schematic/RaspberryPi/3d/raspi v3.step
05_Schematic/esp32/3d/PinHeader_1x12_P2.54mm_Horizontal.step
05_Schematic/esp32/3d/R_1210_3225Metric.step

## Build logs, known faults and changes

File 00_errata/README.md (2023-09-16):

# 正誤表ページです

| ページ  | 内容  | 対象版  |
| ---- | --- | --- |
| P134 | (2)フルサクセスの表　「一部達成(サムネイルのダウンリンクに成功)」→「成功」　「未達成」→「一部達成(一部画像のダウンリンクに成功)」 | 初版  |
| P139 | 表1　部品追加。「54 MissonOBC用電源FET Cystech Electronics Corp.　[MTB30N06I3](https://akizukidenshi.com/catalog/g/gI-15850/) １個　秋月電子」 | 初版  |
| P143 | 表4　2行目「SCA」→「SDA」 | 初版  |
| P144 | 下から9行目　「抵抗0.24Ωをジャンパワイヤで」→「抵抗0.24Ω、リード抵抗10kΩ2本をジャンパワイヤで」 | 初版  |
| P144 | 図11　正しい図は[こちら](image/P144_図11.jpg) | 初版  |
| P145 | 図12　正しい図は[こちら](image/P145_図12.jpg) | 初版  |
| P145 | 図13　正しい図は[こちら](image/P145_図13.jpg) | 初版  |
| P146 | 図14　正しい図は[こちら](image/P146_図14.jpg) | 初版  |
| P147 | (7) ③動作確認 power_mwの式「power_mw = 3.3V ÷ 抵抗 × 3.3V」→「power_mw = 3.3V ÷ 抵抗KΩ × 3.3V」 | 初版・2版  |
| P161 | 図37　正しい図は[こちら](image/P161_図37.jpg) | 初版・2版  |
| P161 | 図38　正しい図は[こちら](image/P161_図38.jpg) | 初版・2版  |
| P163 | 図41　赤丸は電源LEDとなります。正しくは[こちら](image/P163_%E5%9B%B341.png)のLD2となります。 | 初版  |
| P168 | 図51　Q4の配線が間違っていました。正しくは[こちら](image/P168_図51.jpg)となります。 | 初版・2版  |

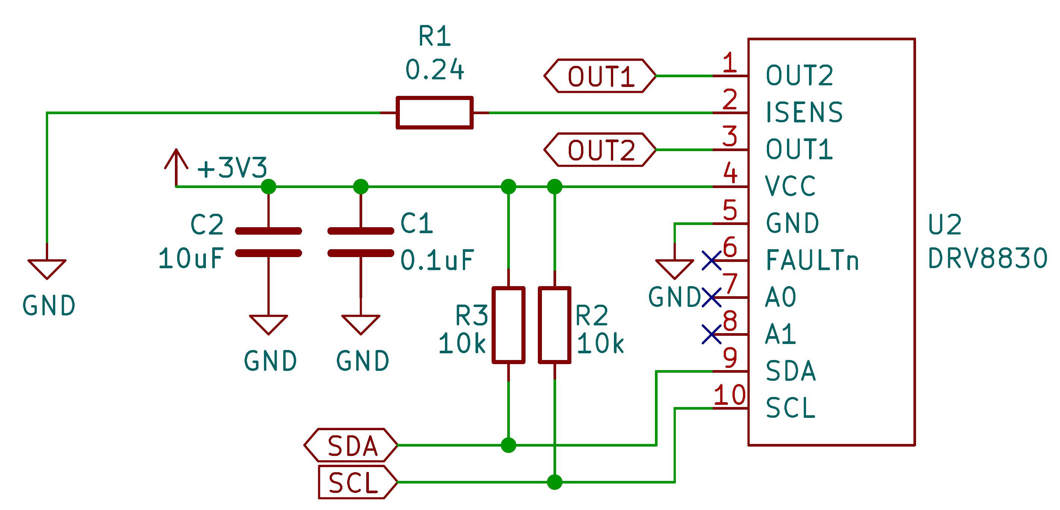
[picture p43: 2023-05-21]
00_errata/image/P145_図13.jpg

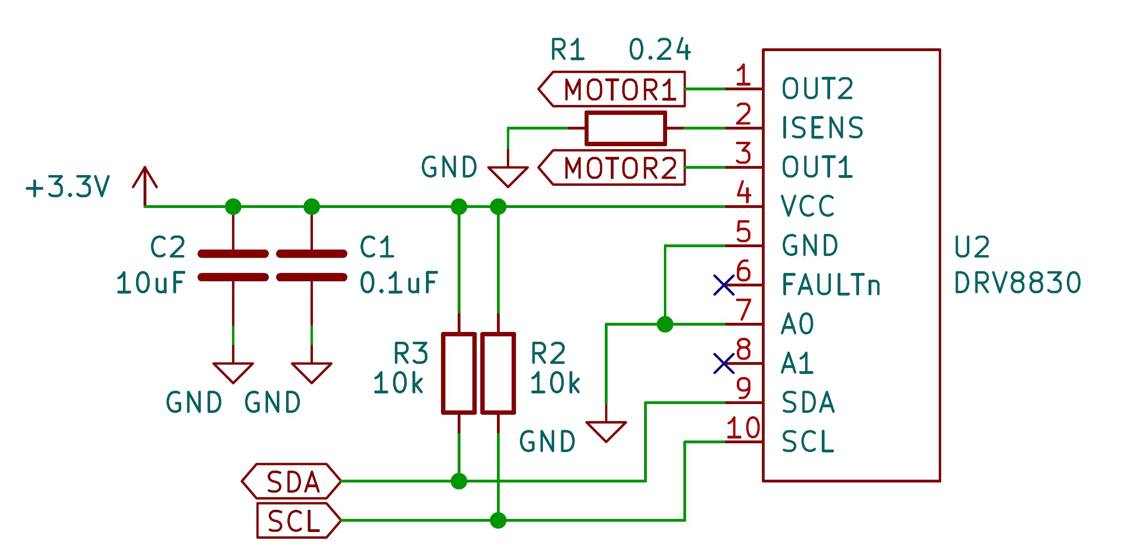
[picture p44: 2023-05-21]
00_errata/image/P144_図11.jpg

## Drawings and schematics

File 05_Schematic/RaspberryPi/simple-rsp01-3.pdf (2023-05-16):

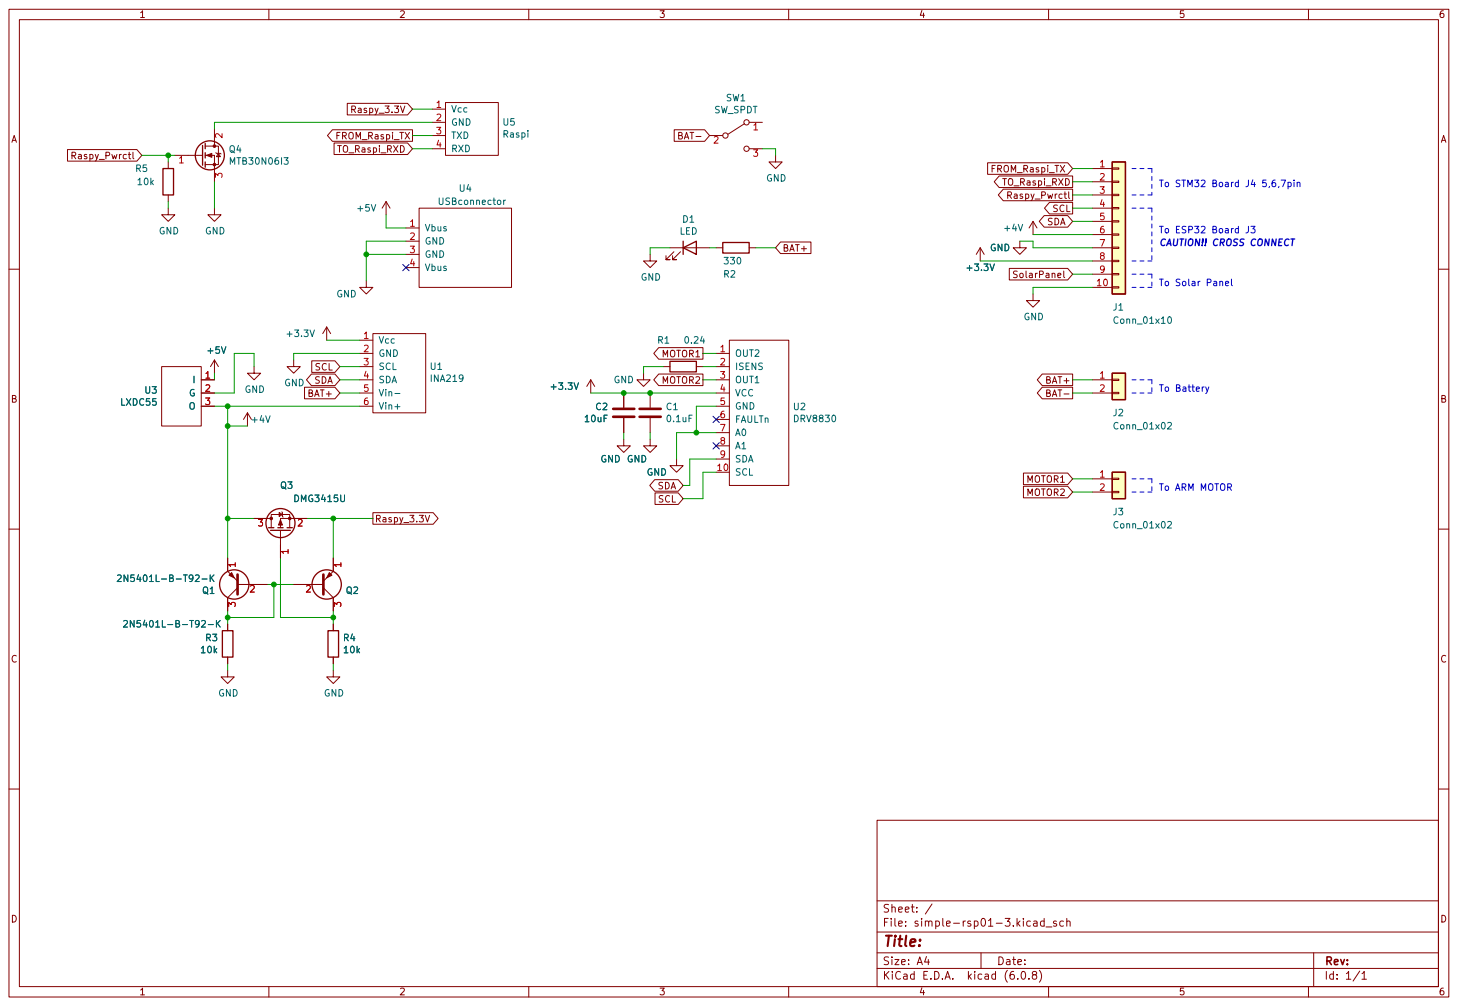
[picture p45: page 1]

To Solar Panel To ESP32 Board J3 CAUTION!! CROSS CONNECT

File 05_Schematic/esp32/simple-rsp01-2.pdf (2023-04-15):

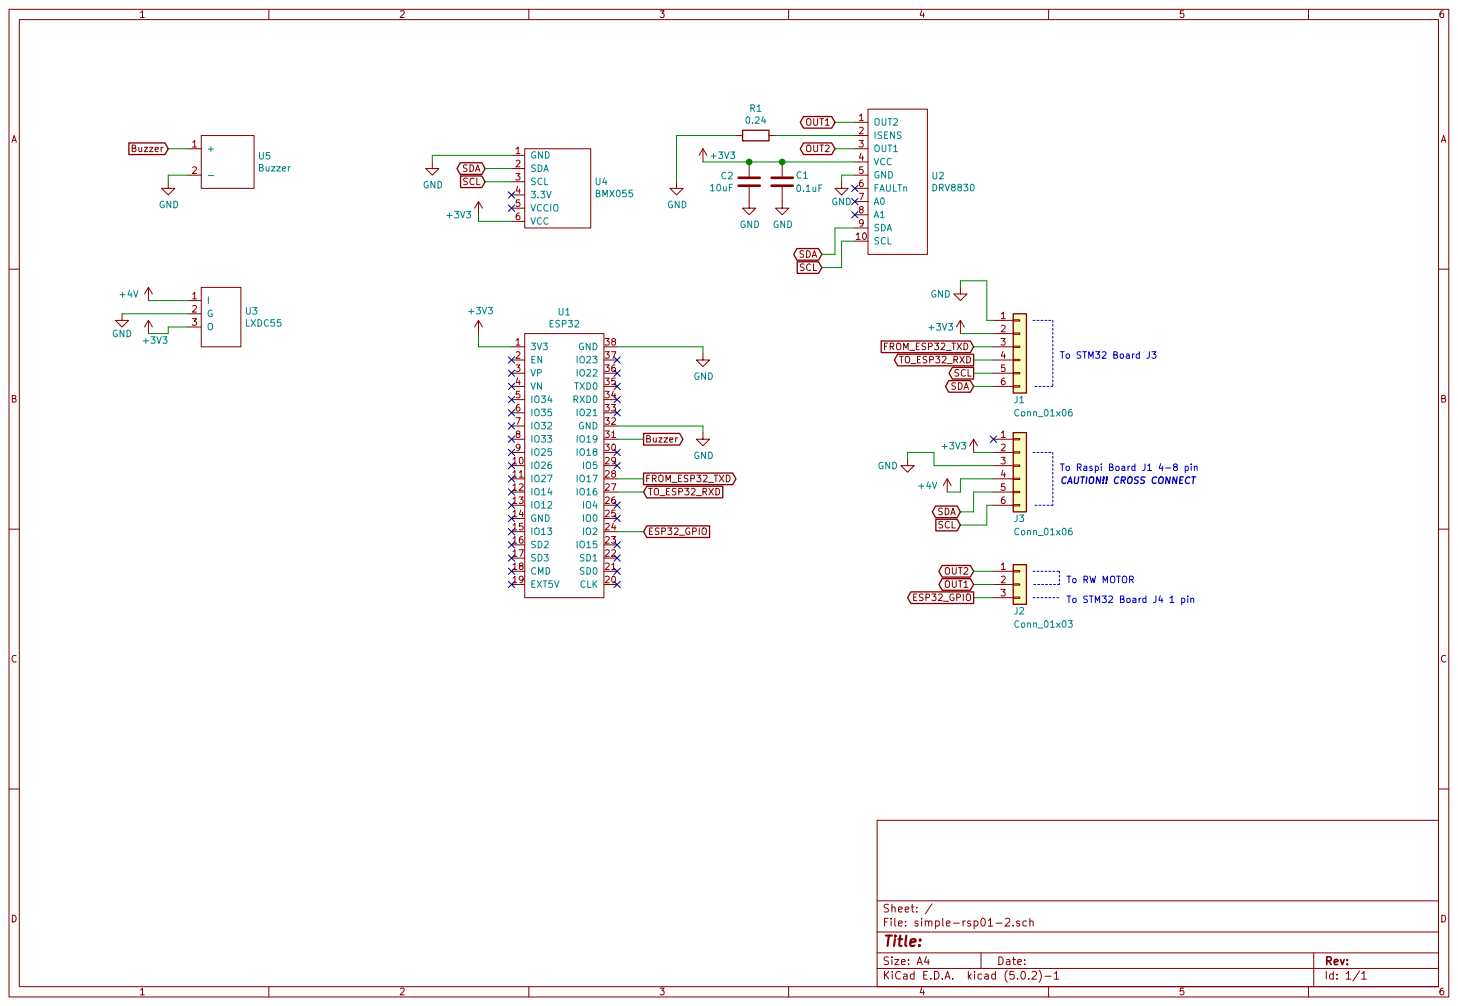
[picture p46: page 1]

To Raspi Board J1 4-8 pin CAUTION!! CROSS CONNECT GND

SCL FROM_ESP32_TXD
To STM32 Board J3 To RW MOTOR

File: simple-rsp01-2.sch Sheet: /
Id: 1/1 Title:

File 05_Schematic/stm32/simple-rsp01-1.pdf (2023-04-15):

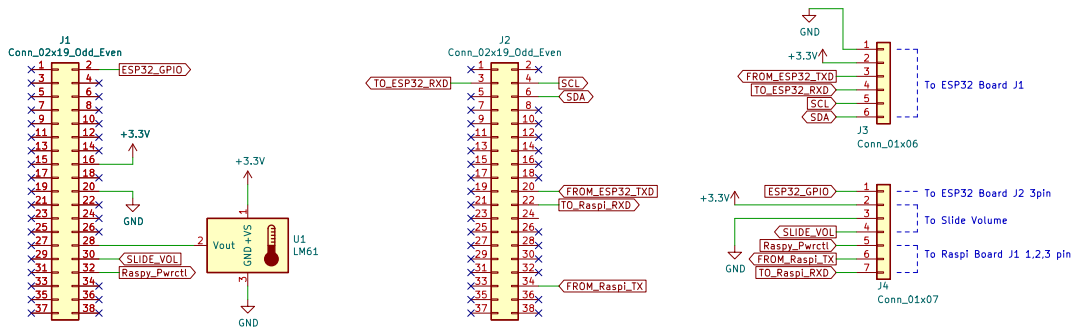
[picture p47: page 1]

To Raspi Board J1 1,2,3 pin

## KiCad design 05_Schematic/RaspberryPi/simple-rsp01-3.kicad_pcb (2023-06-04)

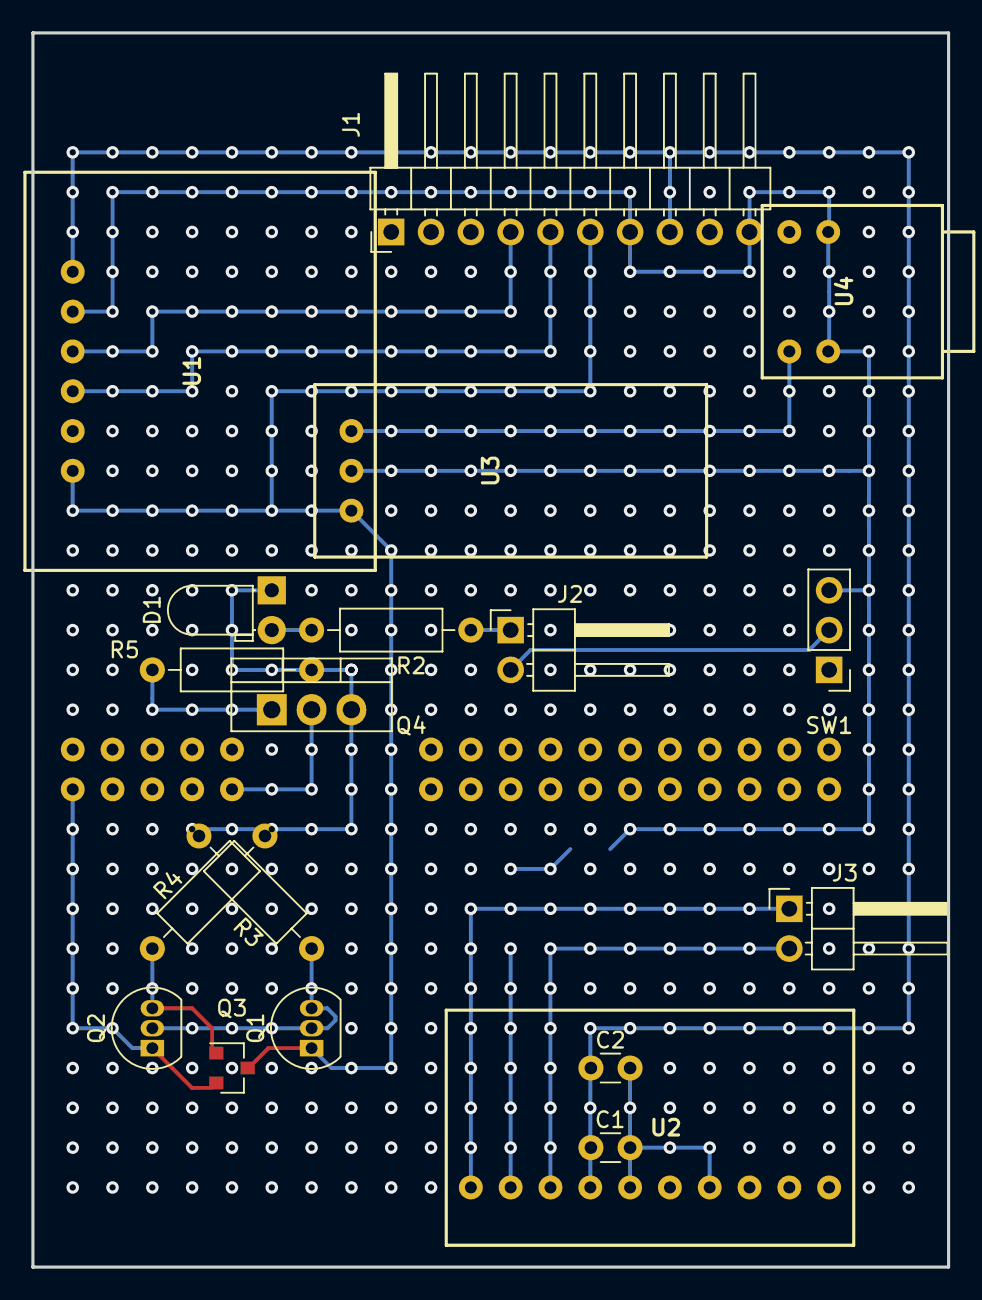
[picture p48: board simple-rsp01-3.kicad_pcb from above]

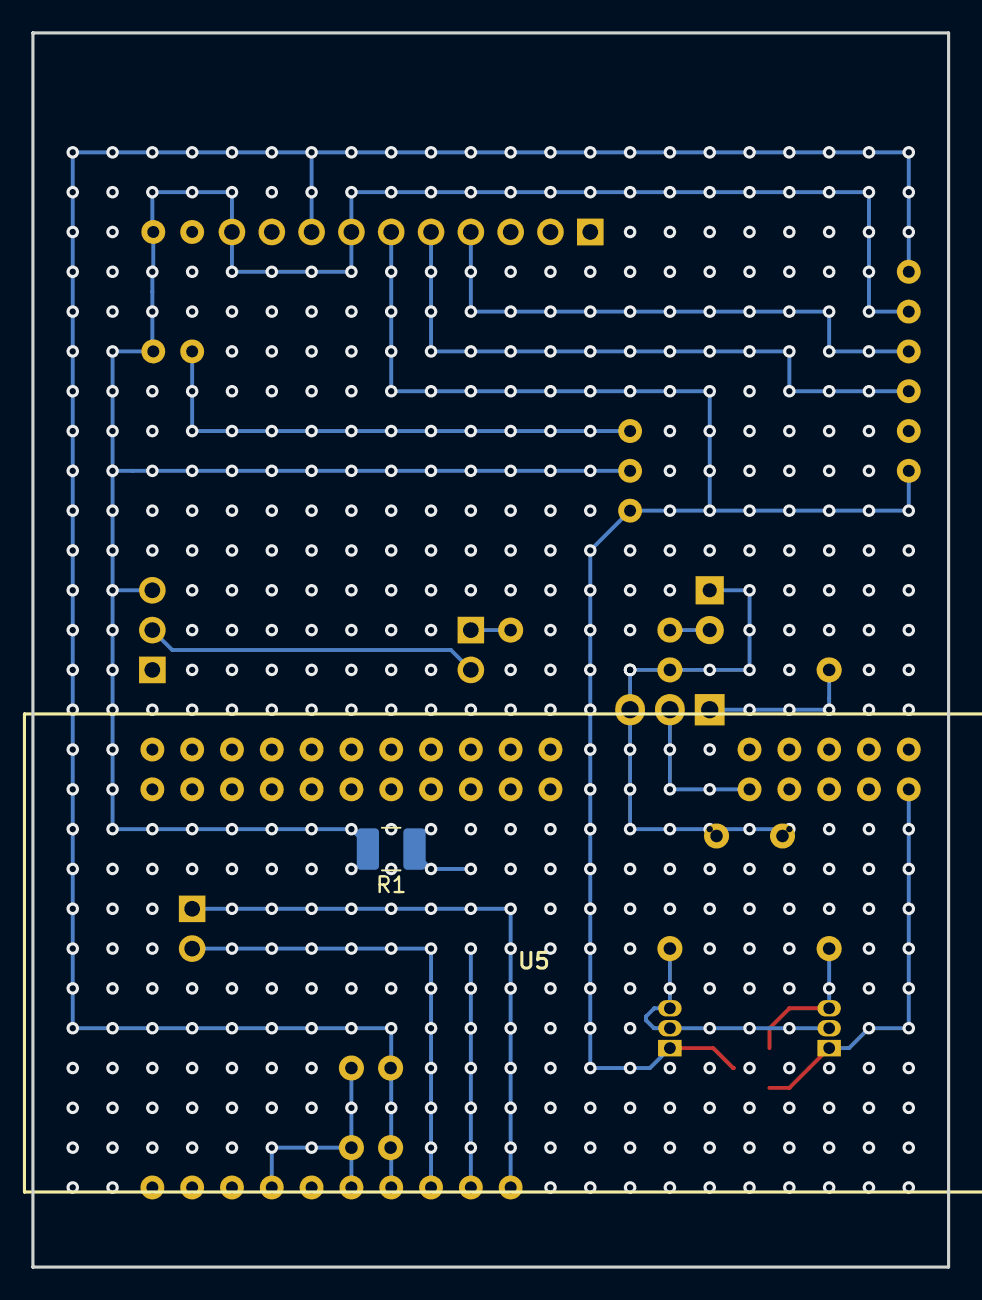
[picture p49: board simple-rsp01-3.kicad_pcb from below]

Board: 2 copper layers, 58.4 x 78.7 mm, 21 parts (2 on the bottom side), 19 nets.

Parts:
C1: 0.1uF; C_Disc_D3.0mm_W1.6mm_P2.50mm
C2: 10uF; C_Disc_D3.0mm_W1.6mm_P2.50mm
D1: LED; LED_D3.0mm_Horizontal_O1.27mm_Z2.0mm
J1: Conn_01x10; PinHeader_1x10_P2.54mm_Horizontal
J2, J3: Conn_01x02; PinHeader_1x02_P2.54mm_Horizontal
Q1, Q2: 2N5401L-B-T92-K; TO-92_Inline
Q3: DMG3415U; SOT-23
Q4: MTB30N06I3; TO-220-3_Vertical
R1: 0.24; R_1210_3225Metric_Pad1.42x2.65mm_HandSolder
R2: 330; R_Axial_DIN0207_L6.3mm_D2.5mm_P10.16mm_Horizontal
R3, R4, R5: 10k; R_Axial_DIN0207_L6.3mm_D2.5mm_P10.16mm_Horizontal
SW1: SW_SPDT; PinHeader_1x03_P2.54mm_Vertical
U1: INA219
U2: DRV8830
U3: LXDC55
U4: USBconnector
U5: Raspi; Raspy

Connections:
+3V3: C1.1, C2.1, J1.8, U1.1, U2.4
+4V: J1.6, Q1.1, Q3.3, U1.6, U3.3
+5V: U3.1, U4.1
BAT+: J2.1, R2.1, U1.5
BAT-: J2.2, SW1.2
FROM_Raspi_TX: J1.1, U5.3
GND: C1.2, C2.2, D1.1, J1.7, J1.10, Q4.3, R1.2, R3.2, R4.2, R5.1, SW1.3, U1.2, U2.5, U2.7, U3.2, U4.2, U4.3
MOTOR1: J3.1, U2.1
MOTOR2: J3.2, U2.3
unnamed: D1.2, R2.2
unnamed: Q1.2, Q1.3, Q2.2, R3.1
unnamed: Q2.3, Q3.1, R4.1
unnamed: Q4.2, U5.2
unnamed: R1.1, U2.2
Raspy_3.3V: Q2.1, Q3.2, U5.1
Raspy_Pwrctl: J1.3, Q4.1, R5.2
SCL: J1.4, U1.3, U2.10
SDA: J1.5, U1.4, U2.9
TO_Raspi_RXD: J1.2, U5.4

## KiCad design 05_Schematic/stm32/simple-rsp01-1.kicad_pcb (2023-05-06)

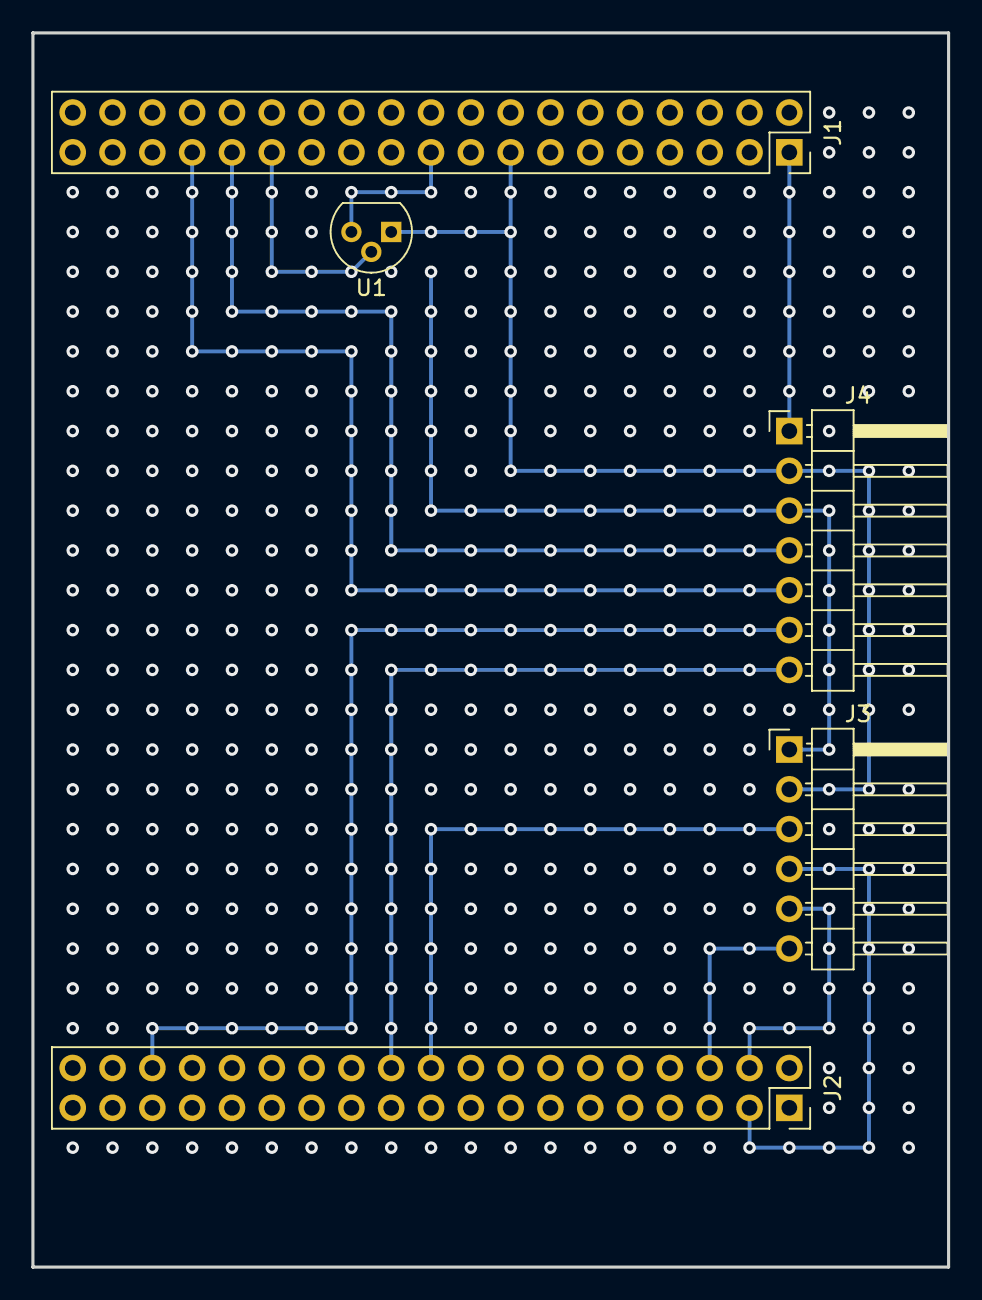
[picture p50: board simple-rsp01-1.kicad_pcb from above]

Board: 2 copper layers, 58.4 x 78.7 mm, 5 parts (0 on the bottom side), 12 nets.

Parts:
J1, J2: Conn_02x19_Odd_Even; PinSocket_2x19_P2.54mm_Vertical
J3: Conn_01x06; PinHeader_1x06_P2.54mm_Horizontal
J4: Conn_01x07; PinHeader_1x07_P2.54mm_Horizontal
U1: LM61; TO-92

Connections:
+3V3: J1.16, J3.2, J4.2, U1.1
ESP32_GPIO: J1.2, J4.1
FROM_ESP32_TXD: J2.20, J3.3
FROM_Raspi_TX: J2.34, J4.6
GND: J1.20, J3.1, J4.3, U1.3
unnamed: J1.28, U1.2
Raspy_Pwrctl: J1.32, J4.5
SCL: J2.4, J3.5
SDA: J2.6, J3.6
SLIDE_VOL: J1.30, J4.4
TO_ESP32_RXD: J2.3, J3.4
TO_Raspi_RXD: J2.22, J4.7

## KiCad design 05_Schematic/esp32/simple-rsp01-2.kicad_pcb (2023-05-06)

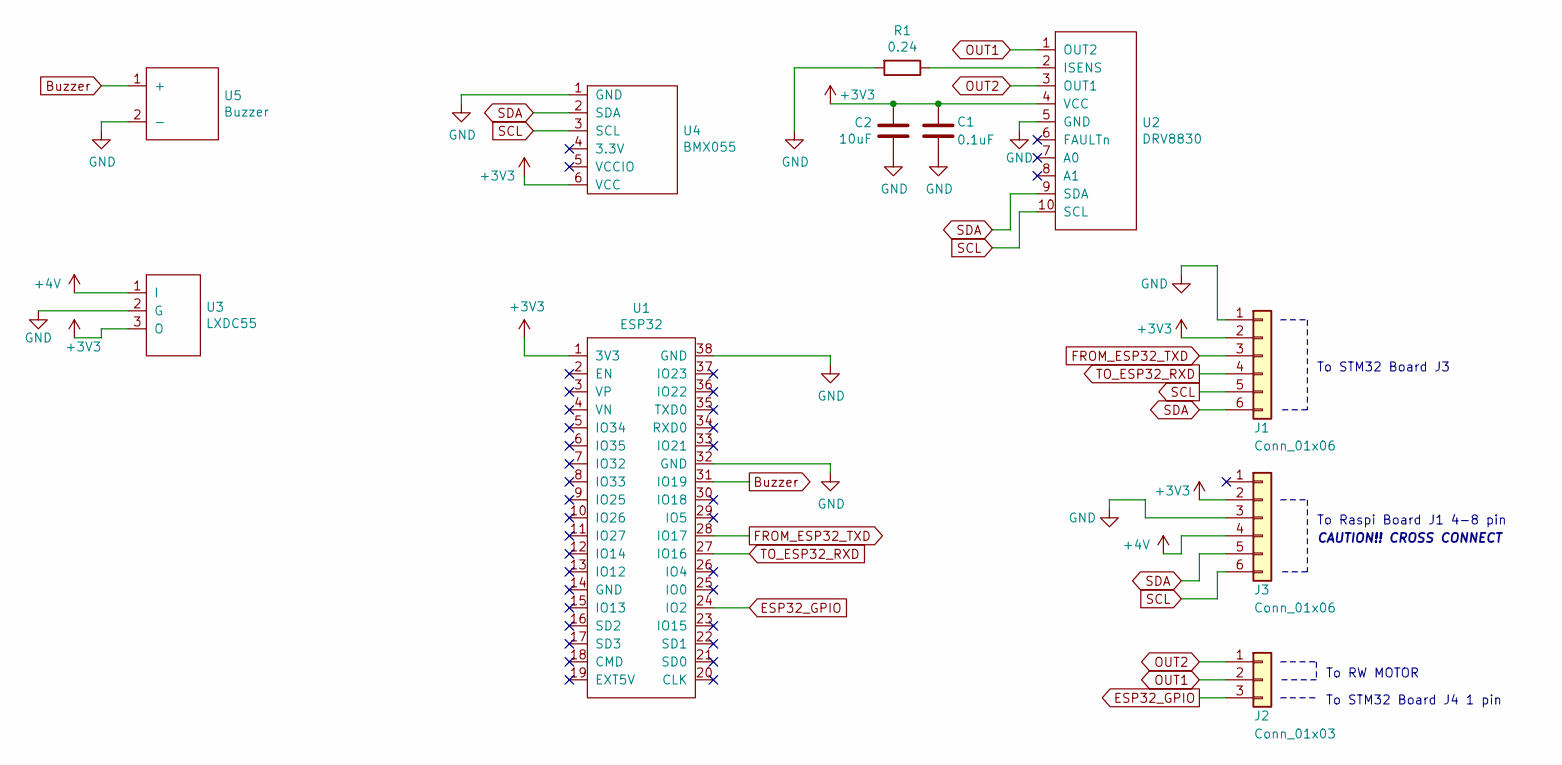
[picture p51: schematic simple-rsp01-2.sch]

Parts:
C1: 0.1uF; C_Disc_D3.0mm_W1.6mm_P2.50mm
C2: 10uF; C_Disc_D3.0mm_W1.6mm_P2.50mm
J1, J3: Conn_01x06; PinHeader_1x06_P2.54mm_Horizontal
J2: Conn_01x03; PinHeader_1x03_P2.54mm_Horizontal
R1: 0.24; R_1210_3225Metric_Pad1.42x2.65mm_HandSolder
U1: ESP32
U2: DRV8830
U3: LXDC55
U4: BMX055
U5: Buzzer

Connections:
+3V3: C1.1, C2.1, J1.2, J3.2, U1.1 (3V3), U2.4 (VCC), U3.3 (O), U4.6 (VCC)
+4V: J3.4, U3.1 (I)
Buzzer: U1.31 (IO19), U5.1 (+)
ESP32_GPIO: J2.3, U1.24 (IO2)
FROM_ESP32_TXD: J1.3, U1.28 (IO17)
GND: C1.2, C2.2, J1.1, J3.3, R1.2, U1.32 (GND), U1.38 (GND), U2.5 (GND), U3.2 (G), U4.1 (GND), U5.2 (-)
unnamed: R1.1, U2.2 (ISENS)
OUT1: J2.2, U2.1 (OUT2)
OUT2: J2.1, U2.3 (OUT1)
SCL: J1.5, J3.6, U2.10 (SCL), U4.3 (SCL)
SDA: J1.6, J3.5, U2.9 (SDA), U4.2 (SDA)
TO_ESP32_RXD: J1.4, U1.27 (IO16)

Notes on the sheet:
To STM32 Board J3
To RW MOTOR
To STM32 Board J4 1 pin
To Raspi Board J1 4-8 pin
CAUTION!! CROSS CONNECT

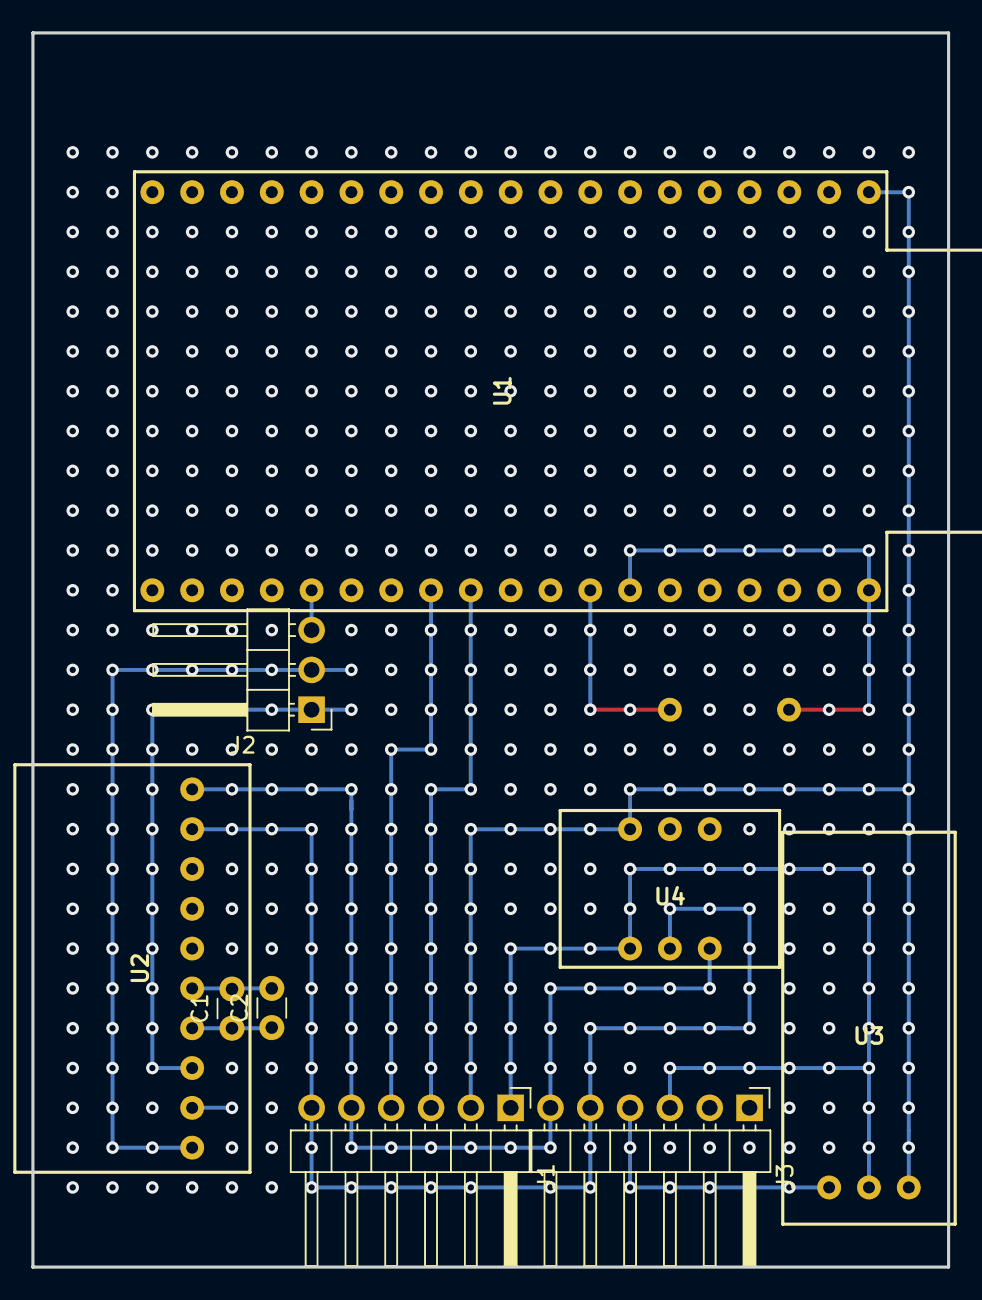
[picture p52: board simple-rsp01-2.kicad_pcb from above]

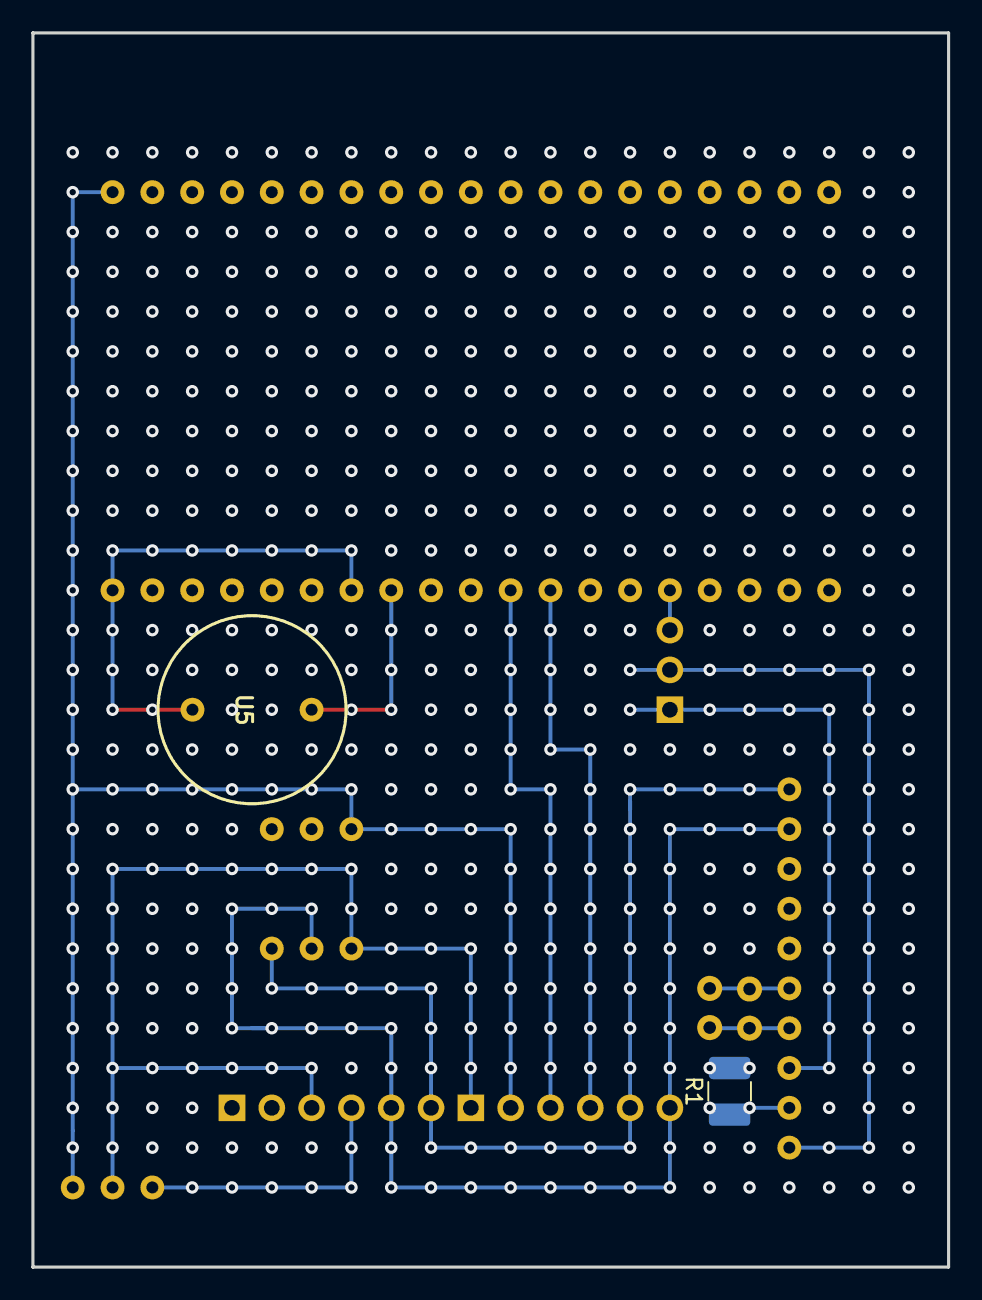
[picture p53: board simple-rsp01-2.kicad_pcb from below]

Board: 2 copper layers, 58.4 x 78.7 mm, 11 parts (2 on the bottom side), 12 nets.

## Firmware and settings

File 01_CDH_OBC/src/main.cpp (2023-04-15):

#include "system/system.hpp"
#include "command/command_param.hpp"
#include "net/net.hpp"
#include "terminal/terminal.hpp"

int main(void) {
    logger_config(VERBOSITY);
    Watchdog::get_instance().start(WATCHDOG_TIMEOUT_MS);

    MainDevice * dev = new MainDevice();
    Power *      power = new Power(dev);
    SpaceSocket *sock = new SpaceSocket(dev->comm);
    HKdata *     hk = new HKdata(dev, power, HKDATA_SIZE);
    Command *    cmd = new Command(dev, hk, power, sock);

    MainSystem sys = {dev, power, hk, cmd, sock};

    HouseKeepingTask *hk_task = new HouseKeepingTask(&sys, 20 * 1000);
    BeaconTask *      beacon_task = new BeaconTask(&sys, 120 * 1000);
    LEDTask *         led_task = new LEDTask(&sys, 1000);
    MainTask *        main_task = new MainTask(&sys, 1000);

    SystemTask *tasks[] = {hk_task, beacon_task, led_task, main_task};

    Serial   *pc = new Serial(USBTX, USBRX);
    Terminal *term = new Terminal(pc, &sys);

    while (true) {
        sys.power->run();

        for (size_t i = 0; i < ARRAY_SIZE(tasks); i++) {
            tasks[i]->run();
        }

        term->run();
    }
}

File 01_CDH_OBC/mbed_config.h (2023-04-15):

/*
 * mbed SDK
 * Copyright (c) 2017 ARM Limited
 *
 * Licensed under the Apache License, Version 2.0 (the "License");
 * you may not use this file except in compliance with the License.
 * You may obtain a copy of the License at
 *
 * http://www.apache.org/licenses/LICENSE-2.0
 *
 * Unless required by applicable law or agreed to in writing, software
 * distributed under the License is distributed on an "AS IS" BASIS,
 * WITHOUT WARRANTIES OR CONDITIONS OF ANY KIND, either express or implied.
 * See the License for the specific language governing permissions and
 * limitations under the License.
 */

// Automatically generated configuration file.
// DO NOT EDIT, content will be overwritten.

#ifndef __MBED_CONFIG_DATA__
#define __MBED_CONFIG_DATA__

// Configuration parameters
#define CLOCK_SOURCE                                                      USE_PLL_HSE_EXTC|USE_PLL_HSI            // set by target:NUCLEO_F401RE
#define LPTICKER_DELAY_TICKS                                              1                                       // set by target:FAMILY_STM32
#define MBED_CONF_APP_MAIN_STACK_SIZE                                     8192                                    // set by application
#define MBED_CONF_DRIVERS_QSPI_CSN                                        QSPI_FLASH1_CSN                         // set by library:drivers
#define MBED_CONF_DRIVERS_QSPI_IO0                                        QSPI_FLASH1_IO0                         // set by library:drivers
#define MBED_CONF_DRIVERS_QSPI_IO1                                        QSPI_FLASH1_IO1                         // set by library:drivers
#define MBED_CONF_DRIVERS_QSPI_IO2                                        QSPI_FLASH1_IO2                         // set by library:drivers
#define MBED_CONF_DRIVERS_QSPI_IO3                                        QSPI_FLASH1_IO3                         // set by library:drivers
#define MBED_CONF_DRIVERS_QSPI_SCK                                        QSPI_FLASH1_SCK                         // set by library:drivers
#define MBED_CONF_DRIVERS_UART_SERIAL_RXBUF_SIZE                          256                                     // set by library:drivers
#define MBED_CONF_DRIVERS_UART_SERIAL_TXBUF_SIZE                          256                                     // set by library:drivers
#define MBED_CONF_PLATFORM_CRASH_CAPTURE_ENABLED                          0                                       // set by library:platform
#define MBED_CONF_PLATFORM_CTHUNK_COUNT_MAX                               8                                       // set by library:platform
#define MBED_CONF_PLATFORM_DEFAULT_SERIAL_BAUD_RATE                       115200                                  // set by application[*]
#define MBED_CONF_PLATFORM_ERROR_ALL_THREADS_INFO                         0                                       // set by library:platform
#define MBED_CONF_PLATFORM_ERROR_FILENAME_CAPTURE_ENABLED                 0                                       // set by library:platform
#define MBED_CONF_PLATFORM_ERROR_HIST_ENABLED                             0                                       // set by library:platform
#define MBED_CONF_PLATFORM_ERROR_HIST_SIZE                                4                                       // set by library:platform
#define MBED_CONF_PLATFORM_ERROR_REBOOT_MAX                               1                                       // set by library:platform
#define MBED_CONF_PLATFORM_FATAL_ERROR_AUTO_REBOOT_ENABLED                0                                       // set by library:platform
#define MBED_CONF_PLATFORM_FORCE_NON_COPYABLE_ERROR                       0                                       // set by library:platform
#define MBED_CONF_PLATFORM_MAX_ERROR_FILENAME_LEN                         16                                      // set by library:platform
#define MBED_CONF_PLATFORM_MINIMAL_PRINTF_ENABLE_64_BIT                   1                                       // set by library:platform
#define MBED_CONF_PLATFORM_MINIMAL_PRINTF_ENABLE_FLOATING_POINT           0                                       // set by library:platform
#define MBED_CONF_PLATFORM_MINIMAL_PRINTF_SET_FLOATING_POINT_MAX_DECIMALS 6                                       // set by library:platform
#define MBED_CONF_PLATFORM_POLL_USE_LOWPOWER_TIMER                        0                                       // set by library:platform
#define MBED_CONF_PLATFORM_STDIO_BAUD_RATE                                115200                                  // set by application[*]
#define MBED_CONF_PLATFORM_STDIO_BUFFERED_SERIAL                          0                                       // set by library:platform
#define MBED_CONF_PLATFORM_STDIO_CONVERT_NEWLINES                         1                                       // set by application[*]
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

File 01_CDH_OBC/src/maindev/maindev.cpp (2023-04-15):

/**
 * @brief
 */

#include "maindev.hpp"
#include "common/common.hpp"

MainDevice::MainDevice() {
    i2c = new I2C(PIN_I2C_SDA, PIN_I2C_SCL);
    serial[0] = new RawSerial(PIN_COMM_TX, PIN_COMM_RX, BAUD_COMM);
    serial[1] = new RawSerial(PIN_RPI_TX, PIN_RPI_RX, BAUD_RPI);

    comm = new Commdev(serial[0], PIN_COMM_INT);
    rpi = new RPi(serial[1]);

    tsens = new Tsens(PIN_TEMP, VREF);
    attsens = new BMX055(i2c);
    powsens = new INA219(i2c);

    arm = new Arm(i2c, PINSTAT_LOW, PINSTAT_HIZ, PIN_ARM);
    rw = new DRV8830(i2c, PINSTAT_HIZ, PINSTAT_HIZ);

    led = new LED(LED1);

    power_rpi = new PinCtrl(PIN_POW_RPI);
    rpi->register_pm(power_rpi);
}

MainDevice::~MainDevice() {
    delete power_rpi;
    delete led;
    delete rw;
    delete arm;
    delete powsens;
    delete attsens;
    delete tsens;
    delete comm;
    delete rpi;

    delete serial[0];
    delete serial[1];
    delete i2c;
}

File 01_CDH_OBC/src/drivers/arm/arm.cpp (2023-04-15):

/**
 * @file
 * @brief
 */

#include "arm.hpp"

constexpr uint8_t POTENTIOMETER_ERROR = 0x40;

constexpr uint32_t VOUT_LIMIT_MV = 3050;
constexpr uint16_t STEP_INTERVAL_TIME_US = 50000;

constexpr uint16_t DRIVE_FORWARD_ERROR_GUARD = 65535;
constexpr uint16_t DRIVE_FORWARD_BRAKE_POINT = DRIVE_FORWARD_LIMIT + 1000;
constexpr uint16_t DRIVE_REVERSE_BRAKE_POINT = DRIVE_REVERSE_LIMIT - 1000;
constexpr uint16_t DRIVE_REVERSE_ERROR_GUARD = 0;

constexpr uint8_t FAULT_MASK = 0x3C;

constexpr uint8_t RET_ERROR = BIT(0);
constexpr uint8_t RET_ERROR_I2C = BIT(7);

Arm::Arm(I2C *i2c, pinstat_t a0, pinstat_t a1, PinName pin_pos)
    : DRV8830(i2c, a0, a1) {
    name = "Camera arm";
    posmeter = new AnalogIn(pin_pos);
    timer = new Timer;
}

Arm::~Arm() {
    delete timer;
    delete posmeter;
}

uint8_t Arm::extend(void) {
    logger_debug("[arm.%s]\n", __func__);
    return drive(MODE_FORWARD);
}

uint8_t Arm::force_extend(uint16_t msec, uint32_t mv) {
    return drive(MODE_FORWARD, msec, mv);
}

uint8_t Arm::fold(void) {
    return drive(MODE_REVERSE);
}

uint8_t Arm::force_fold(uint16_t msec, uint32_t mv) {
    return drive(MODE_REVERSE, msec, mv);
}

uint8_t Arm::drive(uint8_t mode) {
    if (mode != MODE_FORWARD && mode != MODE_REVERSE) {
        return RET_ERROR;
    }

    clear_fault();

    uint16_t pos = position_avg();

    if (is_position_abnormal(pos)) {
        logger_error("[arm.%s] abnormal position: %u\n", __func__, pos);
        return RET_ERROR | POTENTIOMETER_ERROR;
    }

    if ((mode == MODE_FORWARD && pos < DRIVE_FORWARD_LIMIT) ||
        (mode == MODE_REVERSE && DRIVE_REVERSE_LIMIT < pos)) {
        logger_error("[arm.%s] Max position\n", __func__);
        return RET_ERROR;
    }

    // Slow start
    for (uint32_t mv = VOUT_MIN_MV; mv < VOUT_LIMIT_MV;
         mv += VOUT_STEP_MV * 4) {
        control(mv, mode);
        wait_us(STEP_INTERVAL_TIME_US);
        Watchdog::get_instance().kick();
    }

    logger_debug("arm.%s: Step up end\n", __func__);

    control(VOUT_LIMIT_MV, mode);

    uint8_t fault = fault_stat();

    timer->stop();
    timer->reset();
    timer->start();

    int msec_start = timer->read_ms();

    while (true) {
        Watchdog::get_instance().kick();
        wait_us(8000);
        pos = position_avg();

        if (is_position_abnormal(pos)) {
            logger_error("[arm.%s] abnormal position: %u\n", __func__, pos);
            fault = fault | POTENTIOMETER_ERROR;
            break;
        }

        if ((mode == MODE_FORWARD && pos < DRIVE_FORWARD_BRAKE_POINT) ||
            (mode == MODE_REVERSE && DRIVE_REVERSE_BRAKE_POINT < pos)) {
            logger_debug("arm.%s: braking at %d\n", __func__, pos);
            break;
        }

        if (timer->read_ms() - msec_start > DRIVE_TIME_MS) {
            timer->stop();
            timer->reset();
            logger_debug("arm.%s: timeout\n", __func__);
            break;
        }
    }

    for (uint32_t mv = VOUT_LIMIT_MV; mv > VOUT_MIN_MV;
         mv -= VOUT_STEP_MV * 4) {
        control(mv, mode);
        wait_us(STEP_INTERVAL_TIME_US);
        pos = position_avg();

        if (is_position_abnormal(pos)) {
            fault |= POTENTIOMETER_ERROR;
            break;
        }

        if ((mode == MODE_FORWARD && pos < DRIVE_FORWARD_LIMIT) ||
            (mode == MODE_REVERSE && DRIVE_REVERSE_LIMIT < pos)) {
            logger_debug("arm.%s Reached limit: %d\n", __func__, pos);
            break;
        }
    }

    stop();

    logger_debug("arm.%s: Step down end\n", __func__);

    if ((fault & (FAULT_I2C | POTENTIOMETER_ERROR | FAULT_OCCURRED)) == 0) {
        return 0;

    } else if ((fault & FAULT_I2C) != 0) {
        return RET_ERROR | RET_ERROR_I2C;

    } else {
        return RET_ERROR | (fault & FAULT_MASK);
    }
}

uint8_t Arm::drive(uint8_t mode, uint16_t msec, uint32_t mv) {
    if (mode != MODE_FORWARD && mode != MODE_REVERSE) {
        return RET_ERROR;
    }

    logger_debug("arm.%s: V = %d\n", __func__, mv);
    msec = 15000 < msec ? 15000 : msec;

    uint32_t max_mv = clamp<uint32_t>(mv, VOUT_MIN_MV, VOUT_MAX_MV);

    // Slow start
    uint32_t step = (max_mv - VOUT_MIN_MV) / 8;
    step = step <= VOUT_STEP_MV ? VOUT_STEP_MV : step;

    clear_fault();

    for (uint32_t mv = VOUT_MIN_MV; mv < max_mv; mv += step) {
        control(mv, mode);
        wait_us(STEP_INTERVAL_TIME_US);
    }

    logger_debug("arm.%s: Step up end\n", __func__);

    control(max_mv, mode);

    uint8_t fault = fault_stat();

    wait_us(msec * 1000);

    for (uint32_t mv = max_mv; mv > VOUT_MIN_MV; mv -= step) {
        control(mv, mode);
        wait_us(STEP_INTERVAL_TIME_US);
    }

    stop();

    logger_debug("arm.%s: Step down end\n", __func__);

    if ((fault & (FAULT_I2C | FAULT_OCCURRED)) == 0) {
        return 0;
    } else if (fault & FAULT_I2C) {
        return RET_ERROR | RET_ERROR_I2C;
    } else {
        return RET_ERROR | (fault & FAULT_MASK);
    }
}

uint16_t Arm::position_avg(void) {
    uint32_t pos = 0;
    for (int16_t t = 0; t < 8; t++) {
        pos += position();
        wait_us(1000);
    }
    pos = pos / 8;

    logger_debug("arm.%s: Position = %d\n", __func__, pos);
    return (uint16_t)pos;
}

uint16_t Arm::position(void) {
    return posmeter->read_u16();
}

bool Arm::is_position_abnormal(uint16_t pos) {
    if (pos < DRIVE_REVERSE_ERROR_GUARD || DRIVE_FORWARD_ERROR_GUARD < pos) {
        logger_error("%s: Abnormal position: %d\n", __func__, pos);
        return true;
    }

    return false;
}

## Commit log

2023-01-09 地上局ソフト
2023-01-09 7章 簡易RSP-01を作ってみよう補足説明
2023-01-09 各基板図面
2023-04-15 mission init
    [corpus.csv]
2023-04-15 schematic init
    [AE-LXDC55 v7.step, AE-LXDC55-2 v3.step, BMX055 v3.step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]
2023-04-15 errata: LED、zipダウンロード方法
2023-04-15 10_Ch7_Sup init
    [RSP-01Lite部品・工具リスト.xlsx]
2023-04-21 zipの軽量化
2023-04-21 zip軽量化
2023-04-29 Raspberry Piの設定補足を追加
2023-04-29 DD For Windowsのダウンロード方法を追記
2023-04-29 セットアップ開始のプロンプト確認を追加
2023-05-06 正誤表追加
2023-05-06 回路データ更新
    [AE-LXDC55 v7.step, AE-LXDC55-2 v3.step, BMX055 v3.step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]
2023-05-06 デバッグコマンドの修正
2023-05-06 パーツリスト更新
    [RSP-01Lite_Parts_ToolList.xlsx]
2023-05-06 アームに関する説明の追加
2023-05-06 重複ファイルの削除
    [RSP-01Lite部品・工具リスト.xlsx]
2023-05-13 メインOBCの文字入出力の説明の追加
2023-05-16 M系基板の回路図の更新
    [AE-LXDC55-2 v3.step, DRV8830 v2.step, INA219 v1.step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]
2023-05-21 初版での修正画像
2023-05-21 正誤表の更新
2023-05-21 Ubuntu 20.04.6 LTSの注釈を追加
2023-05-23 P.144 図9でBMX055表示が出ない場合
2023-05-27 正誤表 P.161 追加
2023-06-04 Mission基板FET配線誤りの修正
    [C_Disc_D3.0mm_W1.6mm_P2.50mm.step, PinHeader_1x02_P2.54mm_Horizontal.step, PinHeader_1x10_P2.54mm_Horizontal.step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]
2023-06-04 P168 図51 Q4の配線誤りの修正
2023-06-04 代替購入先の追記
    [RSP-01Lite_Parts_ToolList.xlsx]
2023-08-25 コマンドリストを追加
    [RSP-01Lite_CommandList.xlsx]
2023-09-16 エラッタ追加（P147 power_mwの式の修正）
2023-10-08 aptリポジトリの変更

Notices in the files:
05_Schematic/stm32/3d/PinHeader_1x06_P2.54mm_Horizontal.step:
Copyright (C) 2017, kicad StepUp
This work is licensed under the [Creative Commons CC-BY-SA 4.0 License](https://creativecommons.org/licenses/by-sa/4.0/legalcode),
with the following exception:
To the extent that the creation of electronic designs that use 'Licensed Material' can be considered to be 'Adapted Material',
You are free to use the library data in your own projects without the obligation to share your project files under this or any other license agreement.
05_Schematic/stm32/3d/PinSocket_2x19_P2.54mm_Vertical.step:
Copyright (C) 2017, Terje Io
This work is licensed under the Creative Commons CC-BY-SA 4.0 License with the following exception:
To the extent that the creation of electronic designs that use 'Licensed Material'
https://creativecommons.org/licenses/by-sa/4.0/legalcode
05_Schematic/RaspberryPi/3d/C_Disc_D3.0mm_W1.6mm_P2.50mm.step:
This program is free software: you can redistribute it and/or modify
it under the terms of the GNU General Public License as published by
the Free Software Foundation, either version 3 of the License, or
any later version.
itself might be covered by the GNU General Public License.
